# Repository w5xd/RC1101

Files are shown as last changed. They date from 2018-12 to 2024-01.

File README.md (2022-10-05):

# RC1101
Remote control box to add knobs and switches to a PC via USB

3D printed in black and controlling an Elecraft K3 remote.
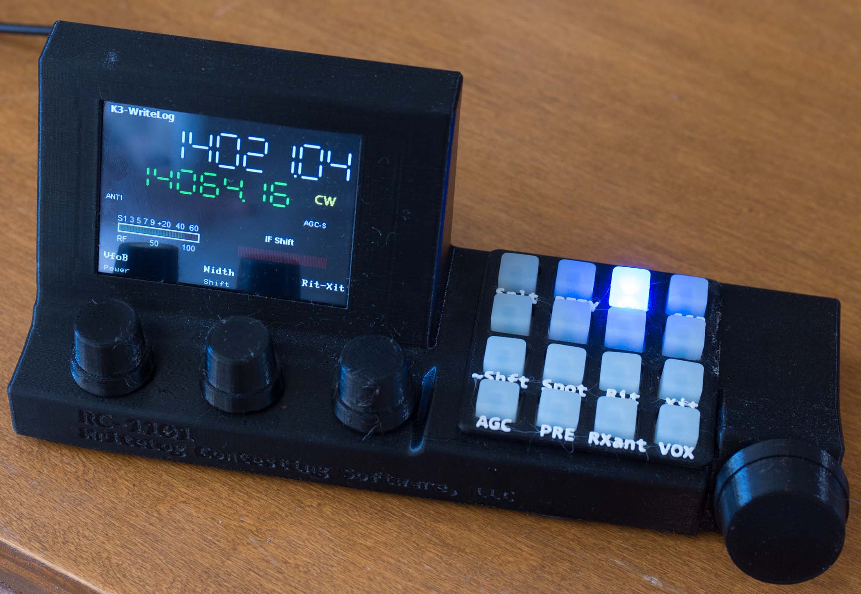
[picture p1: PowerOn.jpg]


This is a build-it-yourself device that WriteLog can use at its control site 
to remote control rigs at your WriteLog-equipped home station. The device can also be used
with WriteLog locally, <i>i.e.</i> at the rig position. (WriteLog restricts your use
of the rig's front panel for the case of RC-1101 control. See the WriteLog documentation.)

Documentation is published here to enable you to:
<ul>
  <li>Fabricate a printed circuit board yourself, or have a service fabricate one for you.</li>
  <li>3D print an enclosure (in three parts.) </li>
  <li>3D print rig-specific keypad overlays</li>
  <li>Parts lists for the remaining, commercially available parts.
  <li>Programming information for its Arduino microprocessor.</li>
  <li>Programming information for its LCD display.</li>
</ul>

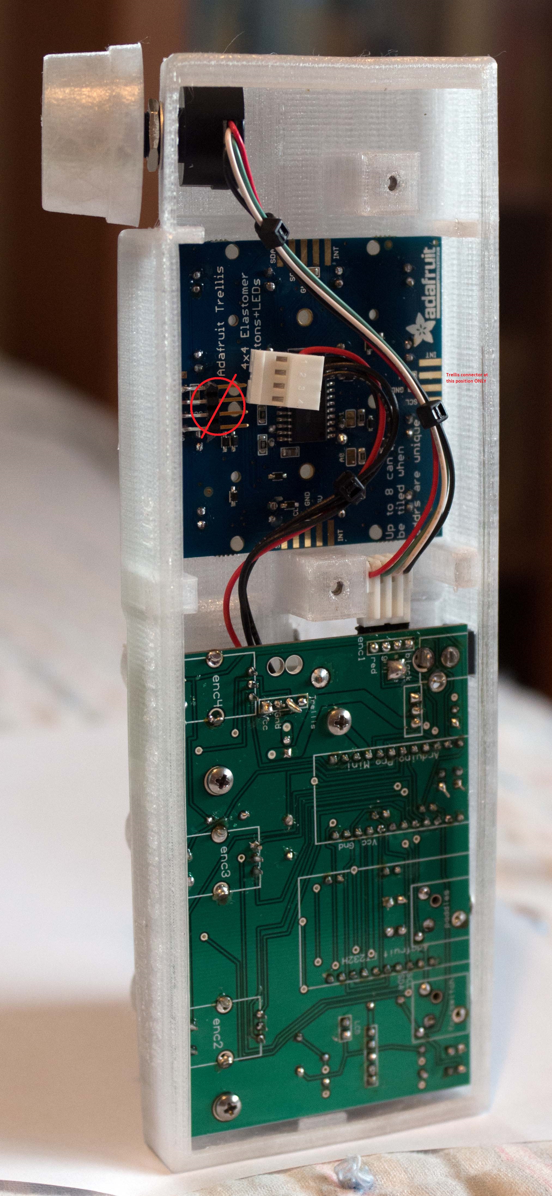
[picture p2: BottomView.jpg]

The enclosure orientation shown&mdash;left hand side down&mdash; is the best one to use for assembly and 
disassembly because the four #4 machine nuts will be retained in their
slots by gravity. Any other orientation risks them falling out.
3D printed using "transparent" PETG. The Adafruit Trellis connector is disconnected for clarity. 
See <a href='construction.md'>construction.md</a> for details.

<h3>Connections</h3>
The back panel has:
<ul>
  <li>DC power. Positive polarity on the center conductor. 7VDC to 9VDC recommended, which dissipates about 1W
  in the TO-220 cased model 7805 5V regulator IC. That part, properly installed with thermal
    grease to the PCB, will stay below 100C up to about 12VDC. The PCB has a 6A rated crowbar
  diode that attempts to protect this circuit against a reverse polarity power supply input. If
    you connect a 35A DC supply to this input backwards...you probably won't like the result.
  </li>
  <li>USB-C. This goes to your PC. WriteLog has support for the RC-1101 over this USB. 
Other software solutions are possible using the open source firmware and PCB on this website. (see <a href='construction.md'>note</a>
about the Adafruit model 2264 old and new. Still-available older parts have micro-USB instead of USB-C,
but both work in the RC1101.)</li>
  <li>Footswitch label on 1/8" phone jack. There is currently no support for this input.</li>
  <li>Paddles label on 1/8" phone jack. There is currently no support for this input.</li>
</ul>
<h3>Printed circuit board</h3>
The layout for the four-layer PCB was done using <a href='http://expresspcb.com'>expresspcb.com</a>.
The file is <a href='WlRemote.rrb'>here</a>.
There are also gerber files <a href='gerber/'>here</a>. 

<h3>Enclosure</h3>
The enclosure was designed using <a href='http://solidworks.com'>Solidworks</a>. 
The Solidworks files are <a href='CAD/'>here</a>.
You don't need Solidworks to print it. The STL files are enough and are
published <a href='STL/'>here</a>. Details about how to print
an enclosure are <a href='enclosure.md'>here</a>.

<h3>Construction hints</h3>
See <a href='construction.md'>this page</a> for construction details.

<br/>Machine screws. 
<ul>
<li>Quantity 8 of #4 by 1/4 inch pan head screws
<li>Quantity 8 of #4 nuts. (square nuts hold in the channel better, but hex nuts fit.)
</ul>

<h3>The keypad, knobs, and LCD</h3>
The Arduino firmware and LCD programming published here work for all supported rigs in a way 
that is customized for each rig. There are conventions in the firmware that at least encourage,
or in some of these cases require, that all rigs behave the same way for these uses:
<ul>
<li>Each button on the keypad represents some function on the rig. Its LED is on to indicate
the function is on, or off otherwise.</li>
<li>The rig driver <i>may</i> program a button to be momentary such that when you press it,
it only blinks on momentarily, and immediately goes back off. This indicates a toggle of 
some function on the remote rig. This is done, for example, for the SPOT function on the 
K3 and K2. Pressing it once turns on the sidetone and pressing it again turns it off.</li>
<li>The biggest knob, to the right, is generally assigned to VFOA, but a given WriteLog
rig driver can change that.</li>
<li>The three smaller knobs not only turn, but also have a momentary contact switch 
that you access by pressing the knob down. The RC-1101 firmware interprets that momentary
press as a command to switch the knob's mode to a second mode. Pressing the switch does not change the
setting of either of the two underlying features on the remote rig.</li>
<li>By convention, the LCD display is programmed to label the knob function at 
the very bottom of its display. And there are two labels for each knob. The
top label is the knob's primary function (the one it has with remote control
is initiated) and the lower label is the secondary function.</li>
<li>The WriteLog rig driver has the capacity to command the RC-1101 as if
you had turned any of its knobs or pressed any of its switches. When the driver
does so, the RC-1101 changes its display state to match. That is, if the driver
commands a button to be pressed, then the LED lights up, in general.
</li>
<li>The LCD display technology is touch sensitive, however the RC-1101
firmware ignores any touches. You may only change the rig by
pressing its switches (the 16 on the keypad, or the 3 under the 
left-hand knobs) or turning its knobs. </li>
</ul>

<h3>Arduino programming</h3>
The device requires the <a href='https://www.sparkfun.com/products/11113'>SparkFun Pro Mini at 5V</a>.
The Arduino sketch is <a href='sketch/wlRemoteGeneric/'>here</a>.

<h3>Gen4-uLCD-32PT programming</h3>
The <a href='https://www.4dsystems.com.au/product/gen4_uLCD_32PT/'>3.2" LCD screen</a> is programmable. The programming 
information is <a href='4D/'>here</a>. The PCB has a 5 pin header with 0.1" spacing to connect to the LCD. It requires the
use of the adapter shipped with the uLCD that converts the 0.5mm FPC cable to 0.1".

<h3>Other</h3>
<a href='WlRemoteCircuit.pdf'>Here</a> is the circuit diagram.

Should you want to use this device without WriteLog, you're going to need
to have some programming on the PC-side of the USB connection to the
RC-1101. <a href='http://github.com/w5xd/RC1101-PC/'>This repository</a> has an example of a .NET program 
for Windows that can access the RC-1101. It uses the libraries
available from <a href='http://ftdichip.com'>ftdichip.com</a>.

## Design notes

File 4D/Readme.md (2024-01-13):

Programming the Gen4-uLCD-32PT for the RC-1101

The LCD device has both a built-in EEPROM program memory and
a micro-SD plugin memory card. The RC-1101 requires <strong>both</strong> be programmed!

Programming the Gen4-uLCD-32PT requires a 4D systems programming cable.
They offer more than one option, and they have changed over time. The
older breakout can program both the old and new LCDs, but the new breakouts have
a connector unique to the Gen4 display.

Use the free IDE from 4D systems to compile the two projects.
https://www.4dsystems.com.au/product/4D_Workshop_4_IDE/

<p>There are (currently) four separate projects to build under the 4D IDE.
The one at Loader32PTU/Loader32PTU.4dg is a loader that you must program into the LCD device
FLASH. It accepts a command over its serial port from the arduino to load a selected
4xe file. This FLASH program in the LCD must be compatible with the ino file in 
the sketch in this same RC1101 source code repository. The other three projects
are rig-specific screen layouts for the RC-1101 LCD.</p>

<p>The workshop files in this directory are identical for those few
RC-1101's built with the older uLCD-32PTU
 device. The 4D Workshop build for the Gen4-uLCD-32PT-AR target as specified in
the .4DGenie projects works fine on those older LCD uSD cards.</p>

The IcomAndFlex.4DGenie project has the screen displays for:
<ul>
<li>A generic form for the case that there is no rig-specific WriteLog driver for the RC-1101.
<li>Icom rigs of the vintage IC-756PRO and newer.
 <li>Flex-6000
</ul>
<p>The 4D workshop build of IcomAndFlex.4DGenie produces a series of files recognizable by their
8.3 DOS file names plus the file IcomAndFlex.4XE.</p>

The TS590andK3.4DGenie has displays for:
<ul>
<li>The same generic form as the above .4D project.
<li>Elecraft K2
<li>Elecraft K3
<li>TS-590
</ul>
<p>The 4D workshop build of TS590andK3.4DGenie produces a series of files recognizable by their
8.3 DOS file names (like the other project above.) And it also creates the file TS590andK3.4xe.
This last file must be renamed TS590.4xe on the uSD card for current WriteLog rig drivers to
specify it. The makeimage.cmd file here does the appropriate file renaming automatically.</p>

The Yaesu.4DGenie has displays for:
<ul>
<li>The same generic form as the above .4D projects.
<li>Recent Yaesu rigs, including the FtDx-10, FtDx-100, FtDX-5000 and others.
</ul>
<p>The 4D workshop build of Yaesu.4DGenie produces a series of files recognizable by their
8.3 DOS file names (like the other project above.) And it also creates the file Yaesu.4xe.</p>

<p>The <code>makeimage.cmd</code> batch file creates a zip file image of what must be copied
to the LCD's uSD card.</p>
<p> The batch file also creates a <code>RunFlash.4xe</code> for 
compatibility with older LCD/Arduino firmware (prior to the WL12.49-Firmware tag in this repository.) 
That older firmware lacks the ability to load a rig-specific 4xe file, and always and only
uses <code>RunFlash.4xe</code>. When you update 
the uSD card on an RC-1101 with the old firmware,  
you must choose which of the rigs it will support by copying the <code>RunFlash.4xe</code>
from one of the 4xe files created above. If you don't know the firmware status,
its safe to copy the appropriate 4xe file to the name <code>RunFlash.4xe</code> on the uSD
card.</p>

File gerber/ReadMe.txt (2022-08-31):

REV02 is obsolete. There is no reason to build it now that REV3 is available.
REV02 has an RC network to filter CW sidetone to the (now obsolete) uLCD-32PTU display.

REV03 is obsolete.
REV03 differs from REV2 in that:
a) it has 4 layers for better RF immunity.
b) it has a place for a 5V sounder for CW sidetone.

REV04 adds SMD pads for all the resistors, capacitors, transistor and regulator

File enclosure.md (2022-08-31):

RC-1101 Enclosure
The enclosure is designed with <a href='https://solidworks.com'>SolidWorks</a>, and the CAD folder is
the SolidWorks design. If you're not going to redesign the enclosure, you
don't need SolidWorks nor what's in the CAD folder. The STL folder contains exported shapes for the enclosures,
<i>almost</i> ready to print on a 3D printer. 
Read the notes below.
The enclosure has these 5 parts to print:
<ol>
	<li>the <a href='STL/enclosure2.STL'>enclosure itself</a>. Do <b>not</b> print this STL file without first 
	understanding exactly what your 3D printer is
       	capable of printing. Do not overlook the cavities
	in the design that accept nuts for #4 nuts. Those cavities are very difficult to clean out if your printing
	process fills them with support material. Hints for printing it on low end
	<a href='https://en.wikipedia.org/wiki/Fused_filament_fabrication#Fused_deposition_modeling'>Fused Deposition Modeling</a> (FDM) printers are below.
	<li><a href='STL/enclosure2 LCD back cover.STL'>enclosure2 LCD back cover.STL</a>
	<li><a href='STL/enclosure2 bottom cover.STL'>enclosure2 bottom cover.STL</a>
	<li><a href='STL/BigKnob.STL'>BigKnob.STL</a>
	<li><a href='STL/SmallKnob.STL'>SmallKnob.STL</a> (print quantity three)
</ol>

In the Trellis directory are the designs for the radio-specific
keypad overlays:
<ul>
	<li><a href='STL/Overlay-Generic.STL'>Overlay-Generic</a> keys used when WriteLog has no specific driver
	<li><a href='STL/Overlay-K2.STL'>Overlay-K2</a> for the Elecraft K2
	<li><a href='STL/Overlay-K3.STL'>Overlay-K3</a> for the Elecraft K3
	<li><a href='STL/Overlay-Icom.STL'>Overlay-Icom</a> For Icom radios, about IC-756 and newer.
</ul>
<h3>Enclosure printing hints</h3>
<p>
The <a href='STL/enclosure2.STL'>enclosure2.STL</a> is the shape you end up with. 
Windows 10 has a viewer for stl. Just click the <a href='STL/enclosure2.STL'>link</a> 
to have a look at it the model. 
On an inexpensive 3D printer, gravity won't let it print in that orientation, and I found I had to model some extra 
supports that break away
after printing. The modeled shape to print on an FDM printer, the one with the orientation that accounts for gravity and
has special supports, is <a href='STL/enclosure42.STL'>enclosure42.STL</a>. 
</p>

<p>Printing this enclosure is not a beginner 3D printing project. It takes a total above 20 hours to print the three of them on my 
<a href='http://prusa3d.com'>prusa I3 MK3S</a> printer. </p>

<p>I used the Prusa recommended slicer, <a href='http://slic3r.org'>Slic3r</a>, to slice the model for printing. The slicer parameters <b>are</b> important for 
the biggest part, <a href='STL/enclosure42.STL'>enclosure42.STL</a>. In particular:</p>
<ol>
	<li>Generate support material is <b>on</b>.</li>
	<li>Support on build plate only is <b>on</b>.</li>
	<li>Various versions of the slicer have given different results with respect to support material. In the current version (PrusaSlicer-2.2.0) I have found that a support material overhang threshold at 20 makes no extra supporting material, but omits the left and right edges of the enclosure. Extra supporting material is a problem because it is difficult to remove. But the left and right edges of the enclosure need supports else they wobble during printing and, at best, have uneven surfaces, but at worse collapse and ruin the print. I used the "support enforcer" option in Slic3r to ensure supporting material on those edges.</li>
	<li>I recommend layer height 0.2mm and the standard 0.4mm nozzle. However, I have successfully printed one in half the time using 0.3mm layer height with a 0.6mm nozzle. But the nut mounting holes are not quite printed square enough, plus it took a lot of my time to fit the LCD into its mounting place because the low resolution print doesn't quite match the shape of the LCD. So use a standard 0.4mm nozzle unless you are practiced with 3D printing and are willing to be extra careful mounting the LCD, and after all that want to save a couple of hours on the printer.</li>
</ol>
The <a href='STL/enclosure2 bottom cover.STL'>enclosure2 bottom cover.STL</a> needs to be printed with:
<ol>
	<li>Generate support material <b>on</b></li>
	<li>Support on build plate only is <b>on</b></li>
	<li>The other cover, <a href='STL/enclosure2 LCD back cover.STL'>enclosure2 LCD back cover.STL</a>, may be printed concurrently. It doesn't need support material but the slicer parameters above won't generate any for the back cover.</li>
</ol>
<p>The three items on this page are the main enclosure. The overlays, and the back and bottom covers can
be printed with default Slic3r settings.  
</p>
I used PETG material for prints destined to actually be used for a device. I used PLA for test prints to 
confirm geometry. A video showing how to remove the support material once printed is posted here:
<p align='center'>
<a href="http://www.youtube.com/watch?feature=player_embedded&v=Ue96Qx1N7DY" target="_blank">youtube Ue96Qx1N7DY</a></p>
<h3>The overlays</h3>
<p>The Trellis keyboard overlays are designed to be printed lettering up with a filament color change anywhere
between Z coordinate above 1.8mm.</p> The text on the overlays comes out far better using a 0.25mm nozzle compared to the standard 0.4mm. I print the overlays with either PLA or PETG filament depending on the color scheme
I want. PETG is the choice when I want the overlay to match the color of its mating enclosure, but PLA is 
easier to deal with, so its a choice for the case you want the overlay printed in a contrasting color.
<h3>Knobs</h3>
All four knobs are for press fit onto a shaft size of 6mm. The 3D printer generally leaves a little debris that can be cleaned out using an undersized drill bit in a bare hand. Rotate the drill bit in the knob's hole while scraping it against all the sides. I used size 15/64 inch.

<h3>Enclosure Cleanup</h3>
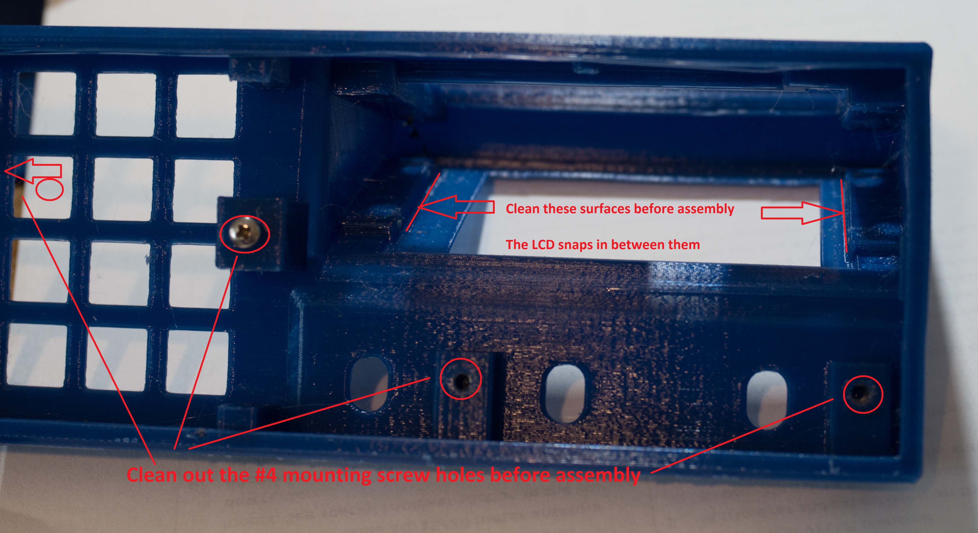
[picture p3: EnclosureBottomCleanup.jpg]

The 3D printing process can leave debris that makes it difficult or impossible to assemble. This
is especially true of the mounting of the LCD. Be sure to use a flat blade screwdriver to
scrape any debris off the surfaces indicated in the photo. Also push a #4 machine screw 
through the 4 mouting holes to clear them as well. Wiggle a small hex key in the nut
slots to loosen the debris.

<h3>Final assembly</h3>
The elastomer pad for the <a href='https://learn.adafruit.com/adafruit-trellis-diy-open-source-led-keypad'>trellis</a> is square, but only two of its possible four orientations lines up its feet into the corresponding holes on its PCB. See this illustration. 
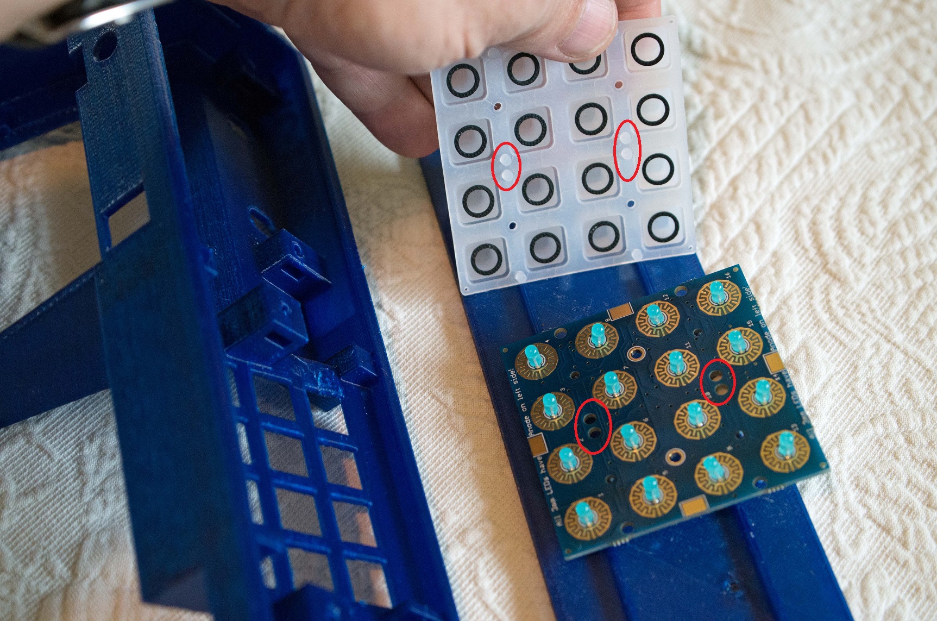
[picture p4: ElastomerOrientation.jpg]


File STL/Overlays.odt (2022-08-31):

Flex-6000

Generic

Icom

K2

K3

TS-590

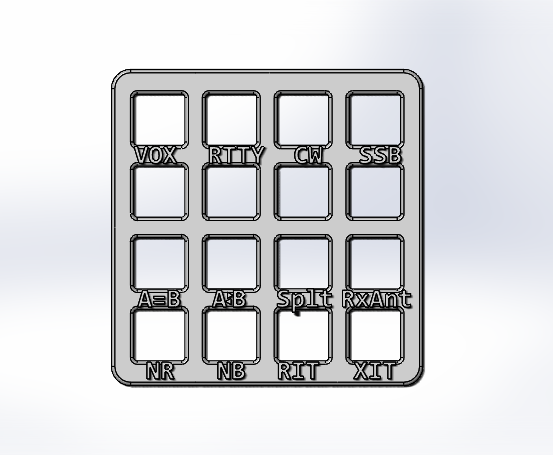
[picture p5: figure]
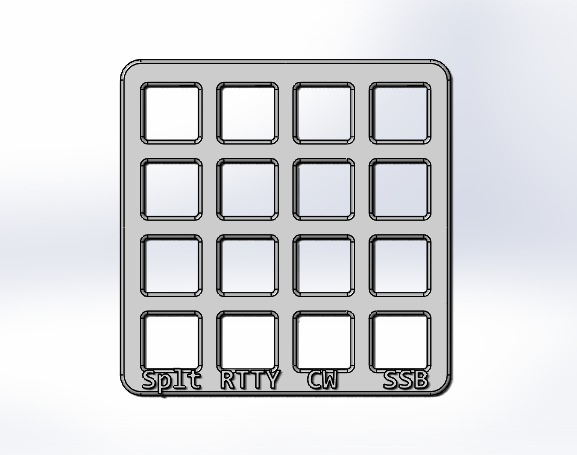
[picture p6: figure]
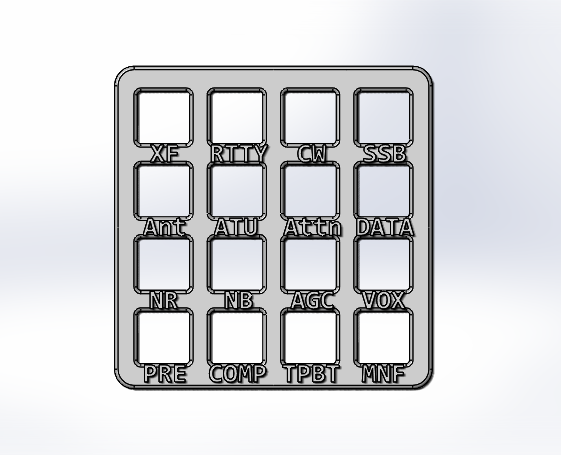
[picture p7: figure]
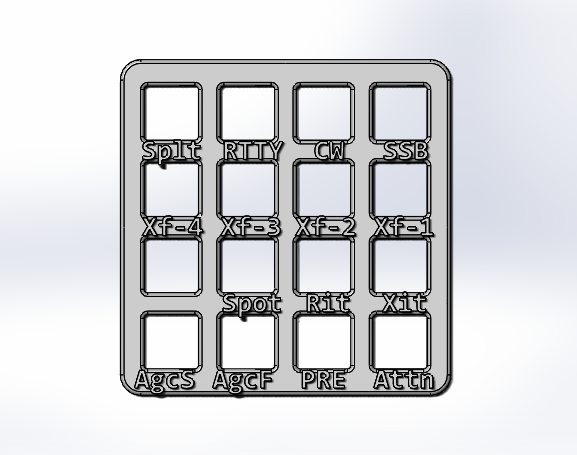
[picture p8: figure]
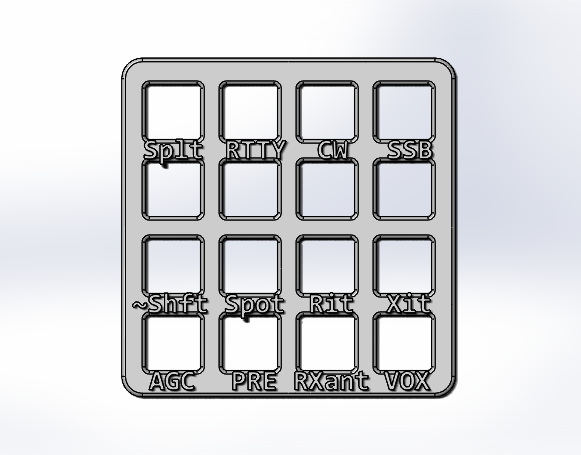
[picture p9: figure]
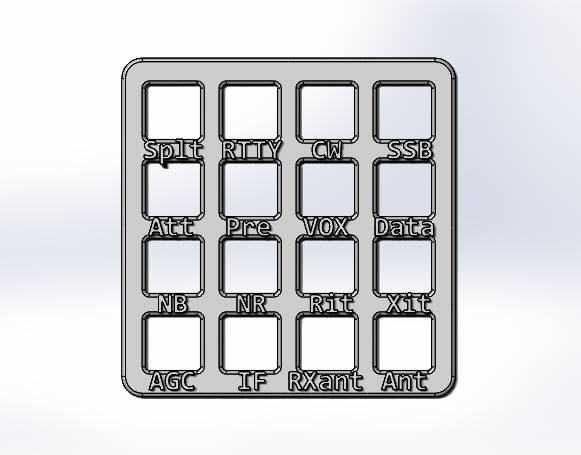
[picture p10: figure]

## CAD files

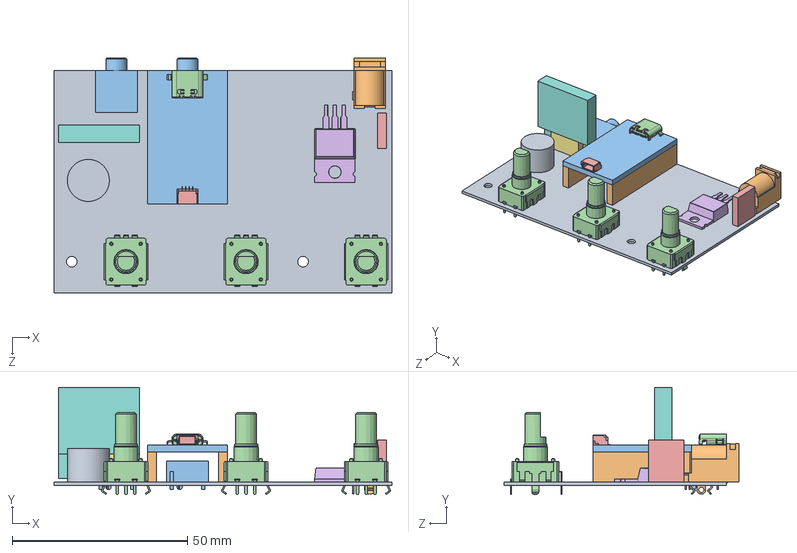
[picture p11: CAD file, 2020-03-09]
CAD/PCB/PcbWithParts.SLDASM
96.5 x 30.6 x 67.0 mm
PCB
CUI_PJ-202A
CUI_SJ-3504 x 2
pec12-encoder x 3
Enc1Header
TO-220 3pins short V1
5PinLcd
gen4-ib
puiaudio
standoff
pcb-ft232
USB-C
quiik

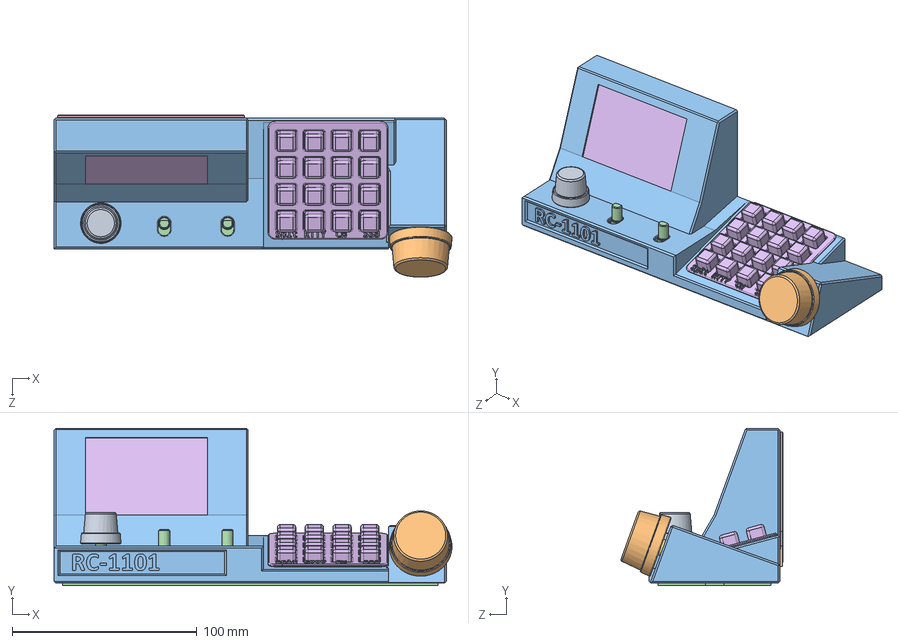
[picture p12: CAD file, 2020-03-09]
CAD/RC1101-4.SLDASM
215.2 x 85.1 x 87.8 mm
PCB
CUI_PJ-202A
CUI_SJ-3504 x 2
pec12-encoder x 3
Enc1Header
TO-220 3pins short V1
5PinLcd
gen4-ib
puiaudio
standoff
pcb-ft232
USB-C
quiik
enclosure2
enclosure2 bottom cover

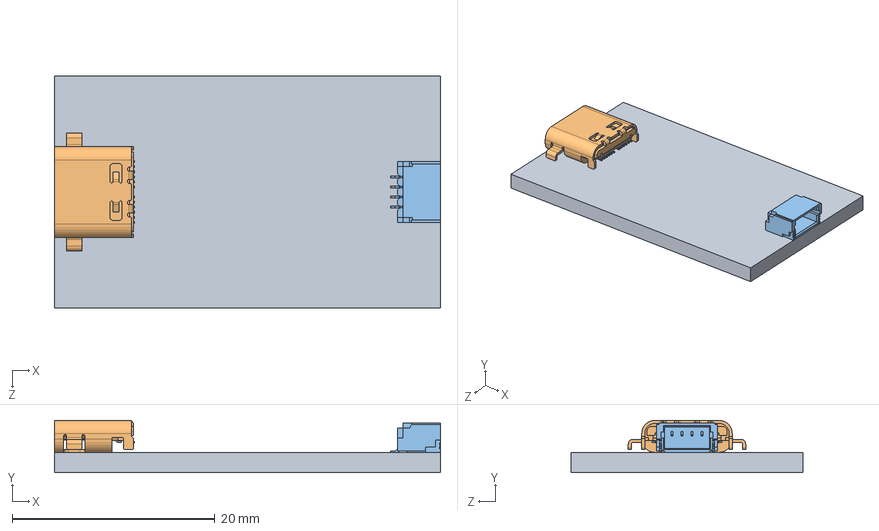
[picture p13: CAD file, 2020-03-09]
CAD/Adafruit232H/Ft232H-2-assembly.SLDASM
38.1 x 5.16 x 22.9 mm
pcb-ft232
USB-C
quiik

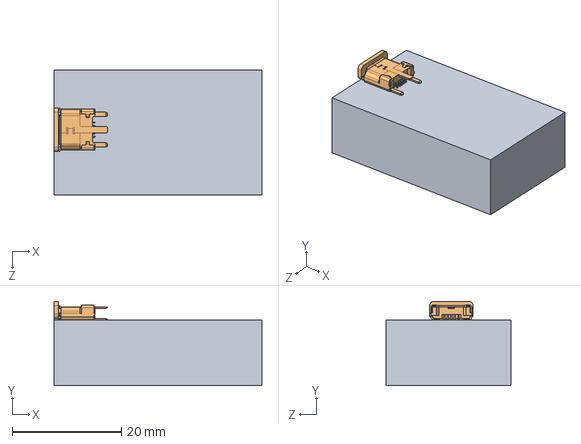
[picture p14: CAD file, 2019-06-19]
CAD/Adafruit232H/Ft232H-assembly.SLDASM
38.1 x 15.4 x 22.9 mm
StandingOff

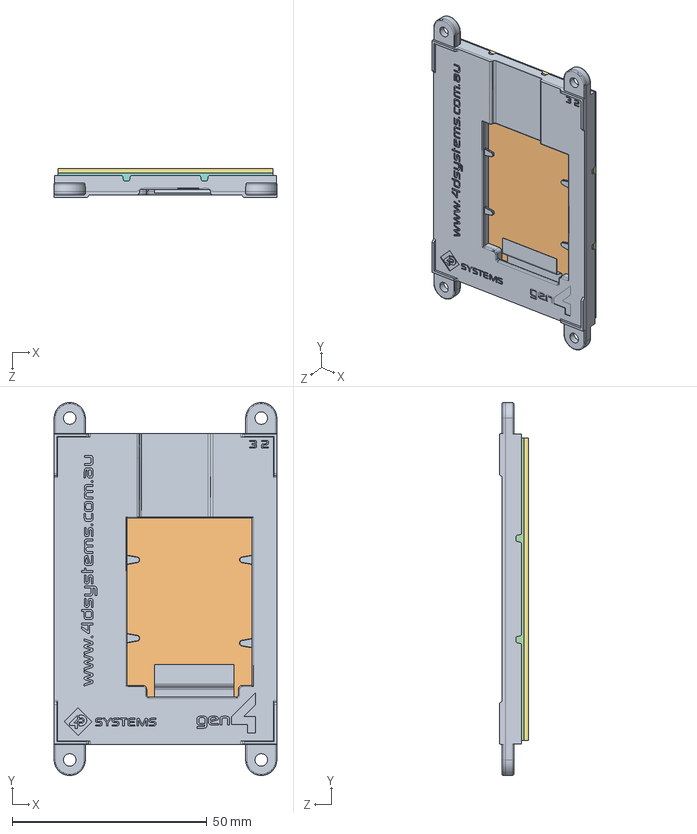
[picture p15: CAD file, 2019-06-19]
CAD/LCD/gen4/Assembly-32PT-NoPCB_2.sldasm
57.1 x 95.7 x 7.49 mm
gen4-32-PT_2
4DLCD-32T-QVGA-BASE
4DLCD-32T-QVGA-LCDGLASS
4DLCD-32T-QVGA-METAL
4DLCD-32T-QVGA-BASE_1
4DLCD-32T-QVGA-LCDGLASS_1
4DLCD-32T-QVGA-GLASS-RTP_1
4DLCD-32T-QVGA-METAL_1
4DLCD-32T-QVGA-FLEX-Gen4_1

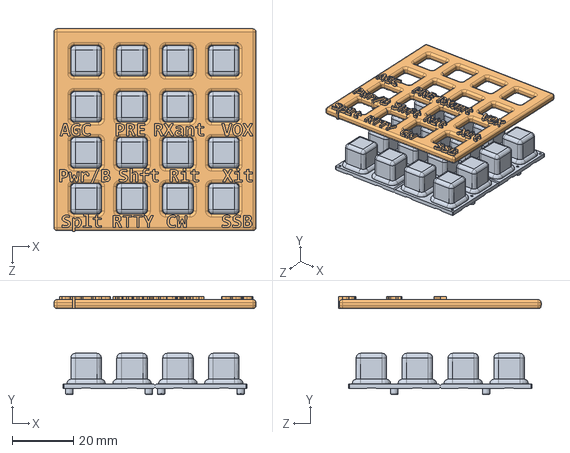
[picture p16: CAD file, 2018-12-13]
CAD/Trellis/TrellisOverlay.SLDASM
66.0 x 32.0 x 66.2 mm
Adafruit Trellis 3mm
Overlay-K3

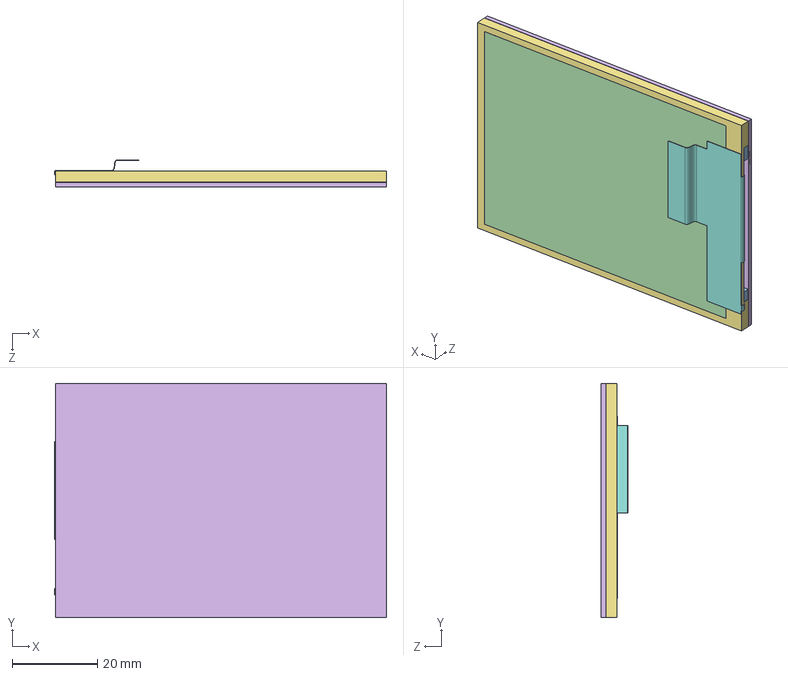
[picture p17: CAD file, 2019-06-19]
CAD/LCD/gen4/4DLCD-32T-QVGA-LCD_2.sldasm
78.0 x 55.0 x 6.37 mm
4DLCD-32T-QVGA-BASE
4DLCD-32T-QVGA-LCDGLASS
4DLCD-32T-QVGA-METAL
4DLCD-32T-QVGA-BASE_1
4DLCD-32T-QVGA-LCDGLASS_1
4DLCD-32T-QVGA-GLASS-RTP_1
4DLCD-32T-QVGA-METAL_1
4DLCD-32T-QVGA-FLEX-Gen4_1

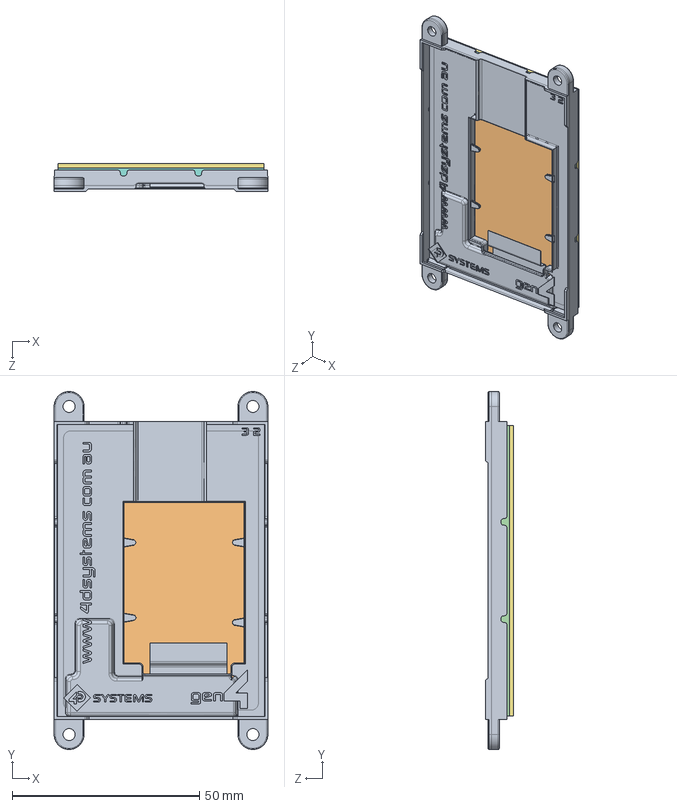
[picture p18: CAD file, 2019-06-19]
CAD/LCD/gen4/gen4-uLCD-32PT.SLDASM
57.1 x 95.7 x 7.49 mm
gen4-32-PT_2
4DLCD-32T-QVGA-LCDGLASS
4DLCD-32T-QVGA-LCDGLASS_1
4DLCD-32T-QVGA-GLASS-RTP_1

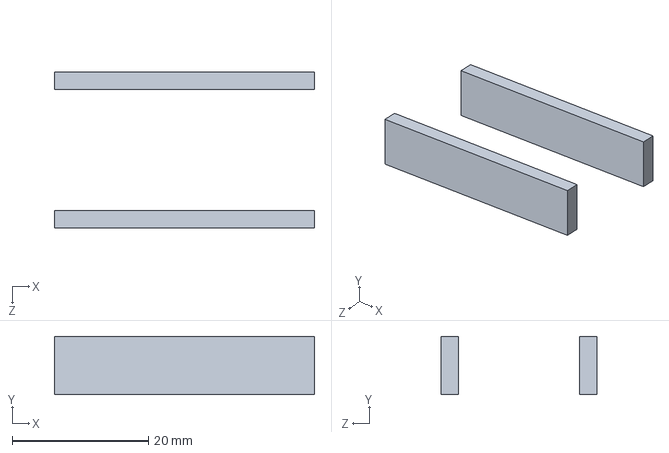
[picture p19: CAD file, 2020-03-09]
CAD/Adafruit232H/standoff.sldprt
38.1 x 8.50 x 22.9 mm

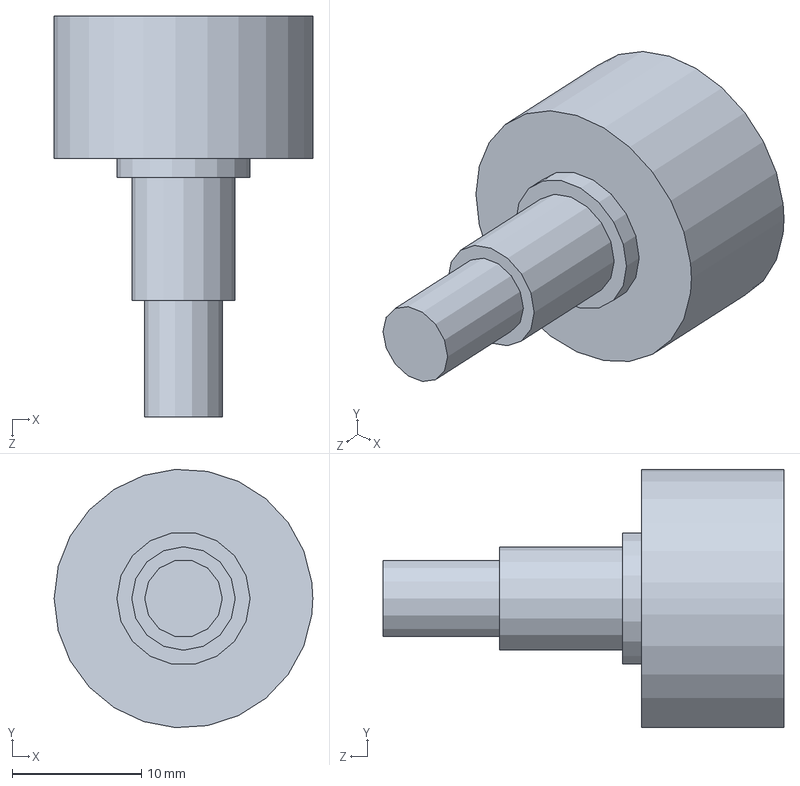
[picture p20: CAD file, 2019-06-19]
CAD/Copal/Copal-encoder.SLDPRT
20.0 x 20.0 x 31.0 mm

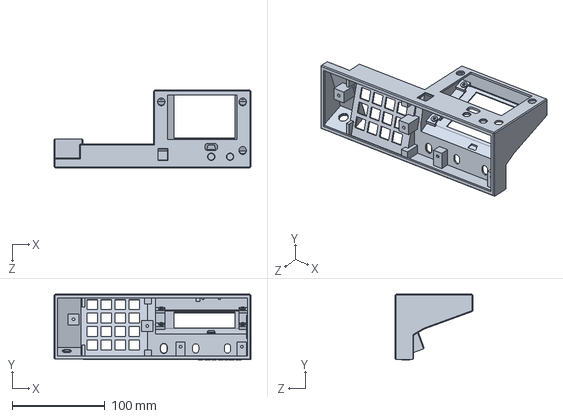
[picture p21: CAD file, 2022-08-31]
CAD/Enclosure/enclosure2.sldprt
212.2 x 70.9 x 83.7 mm

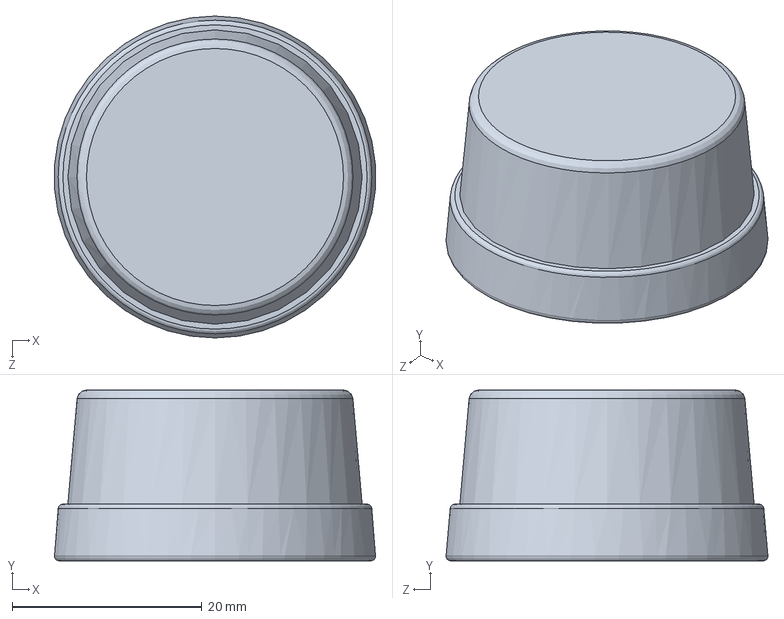
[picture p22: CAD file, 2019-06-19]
CAD/knobs/BigKnob.SLDPRT
33.8 x 18.0 x 33.9 mm

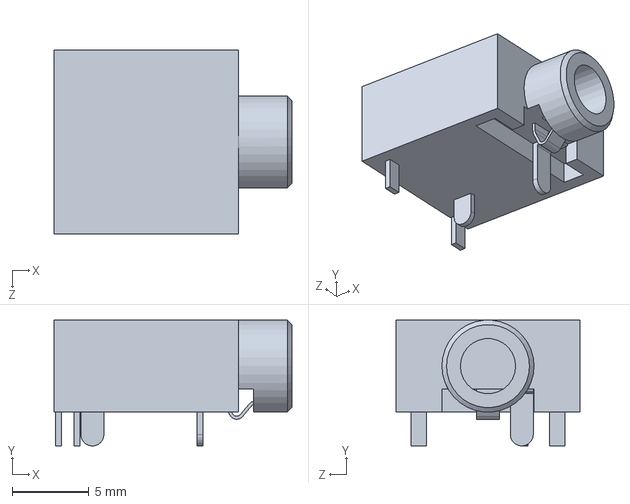
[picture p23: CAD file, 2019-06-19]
CAD/pec12/CUI_SJ-3504.sldprt
15.5 x 8.20 x 12.0 mm

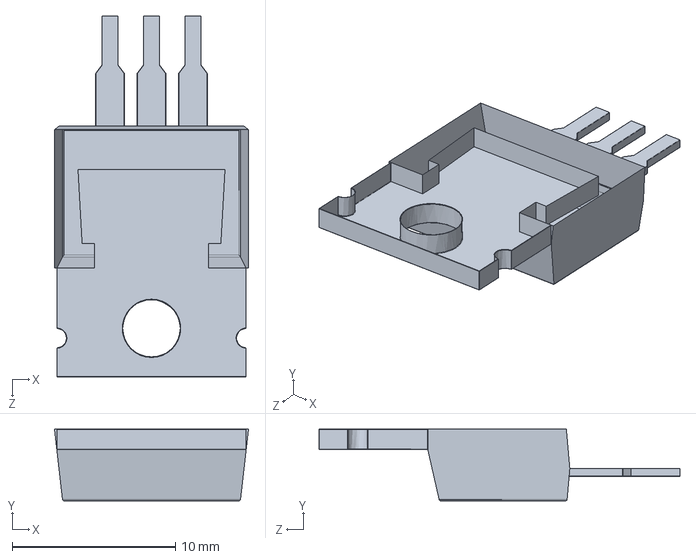
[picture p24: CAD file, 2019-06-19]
CAD/TO220/TO-220 3pins short V1.SLDPRT
11.9 x 4.40 x 22.1 mm

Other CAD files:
CAD/LCD/gen4/4DLCD-32T-QVGA-GLASS-RTP_1.sldprt
CAD/Trellis/Overlay-Blank.stp
STL/Overlay-Generic.STL
CAD/Adafruit232H/StandingOff.SLDPRT
CAD/Adafruit232H/1051330001.SLDPRT
CAD/Adafruit232H/1051330001.stp
CAD/Adafruit232H/USB-C.SLDPRT
CAD/Adafruit232H/USB-C.stp
CAD/Adafruit232H/pcb-ft232.SLDPRT
CAD/Adafruit232H/quiik.SLDPRT
CAD/Adafruit232H/quiik.stp
CAD/Enclosure/enclosure2 LCD back cover.sldprt
CAD/Enclosure/enclosure2 bottom cover.sldprt
CAD/LCD/gen4/4DLCD-32T-QVGA-BASE.sldprt
CAD/LCD/gen4/4DLCD-32T-QVGA-BASE_1.sldprt
CAD/LCD/gen4/4DLCD-32T-QVGA-FLEX-Gen4.sldprt
CAD/LCD/gen4/4DLCD-32T-QVGA-FLEX-Gen4_1.sldprt
CAD/LCD/gen4/4DLCD-32T-QVGA-GLASS-RTP.sldprt
CAD/LCD/gen4/4DLCD-32T-QVGA-LCDGLASS.sldprt
CAD/LCD/gen4/4DLCD-32T-QVGA-LCDGLASS_1.sldprt
CAD/LCD/gen4/4DLCD-32T-QVGA-METAL.sldprt
CAD/LCD/gen4/4DLCD-32T-QVGA-METAL_1.sldprt
CAD/LCD/gen4/gen4-32-PT_2.sldprt
CAD/PCB/5PinLcd.SLDPRT
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

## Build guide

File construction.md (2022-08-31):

<h3>Parts List</h3>
<p>See a PDF of the parts <a href='partslist.pdf'>here</a>. Or link to the digikey shared shopping cart from 
<a href='https://www.digikey.com/short/z84fb8'>here</a>.</p>
<p>Note that the specified female headers have a 0.29 inch insulation height. This, combined with the 0.10 inch insulation height on the matching male header, is a critical dimension
for the Adafruit FT232H breakout board. The USB port on that board will not line up with its matching hole 
in the enclosure otherwise. Also note that Adafruit has put their same part number, 2264, on both an older 
version of the board with a micro-USB connector,
and a newer version with a USB-C connector. Both the old and new Adafruit boards will fit this PCB and 
enclosure, but of course you'll need a different cable.</p>

<h3>Construction hints</h3>
<p>
Fully assemble the two printed circuit boards. </p>
<p>The custom 3.5 inch by 2.8 inch printed circuit board has holes for through-hole components at all
positions combined with SMD 1206 pads for all the resistors and capacitors plus SMD pads for
the transistor, voltage regulator and crowbar diode. We don't
offer step-by-step kit instructions, but here is an order of assembly that accommodates being able to
place the through-hole components and solder them without them falling out (much). The photos
below do not exactly match the order the text describes installing the components. The order is not
critical, except that taller components should be installed later, and the resistors and capacitors
can be installed almost any time without interference with other components. </p>
<ul>
<li>If you're using SMD components, apply solder paste and place all the resistors, capacitors, transistor,
voltage regulator, and crowbard diode and reflow solder them. And skip the steps below describing when to
install them through-hole.</li>
<li>Instructions for the Adafruit Trellis are
<a href='https://learn.adafruit.com/adafruit-trellis-diy-open-source-led-keypad/adding-leds'>here</a>.</li>
<li>Add the right angle 4 pin SMD header. There are four sets of pads that look like you can connect but <i><strong>the position in the photo is the only position it will fit in the enclosure.</strong></i>
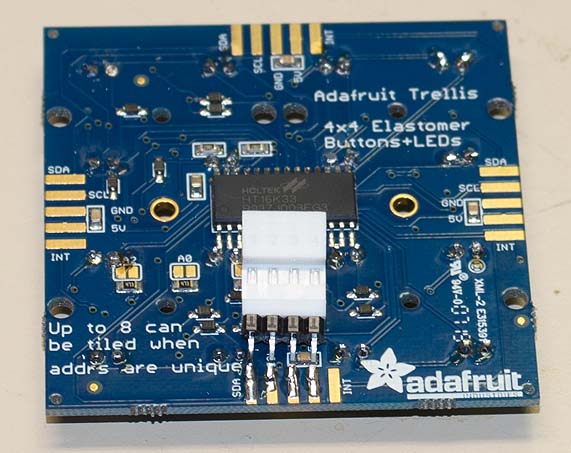
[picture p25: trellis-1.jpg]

Temporarily place the 4-pin connector as a spacer to ensure you have room to install it later.
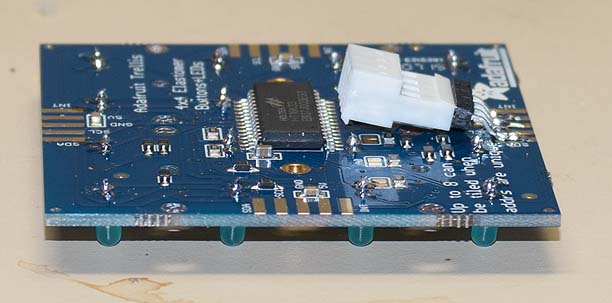
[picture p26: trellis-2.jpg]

 </li>
<li>Smallest parts go on the PCB first.
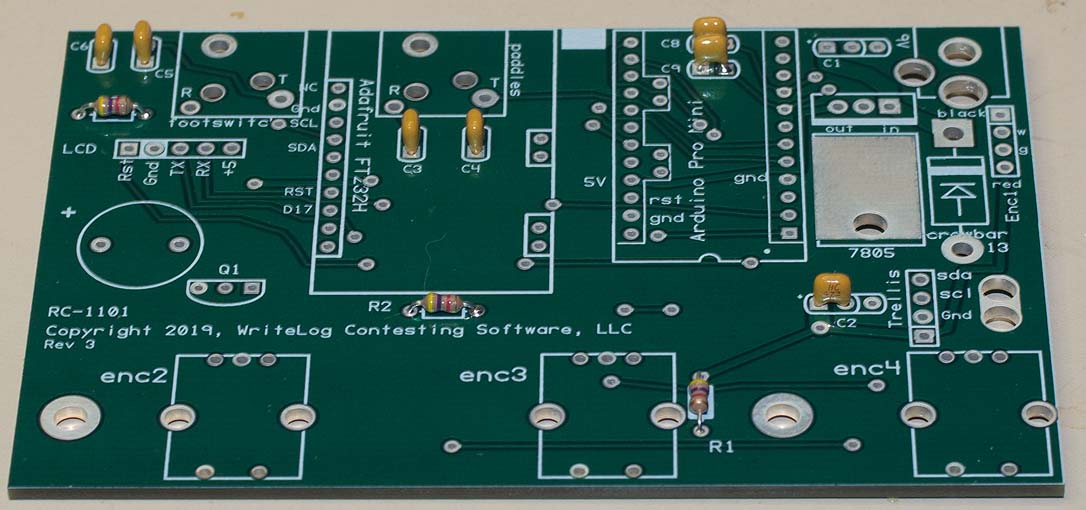
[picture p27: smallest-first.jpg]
</li>
<li>Install a right angle male header at enc-1. The pins extend out beyond the edge of the PCB.
	<li>the two 1/8" mini jacks, J2 and J2.
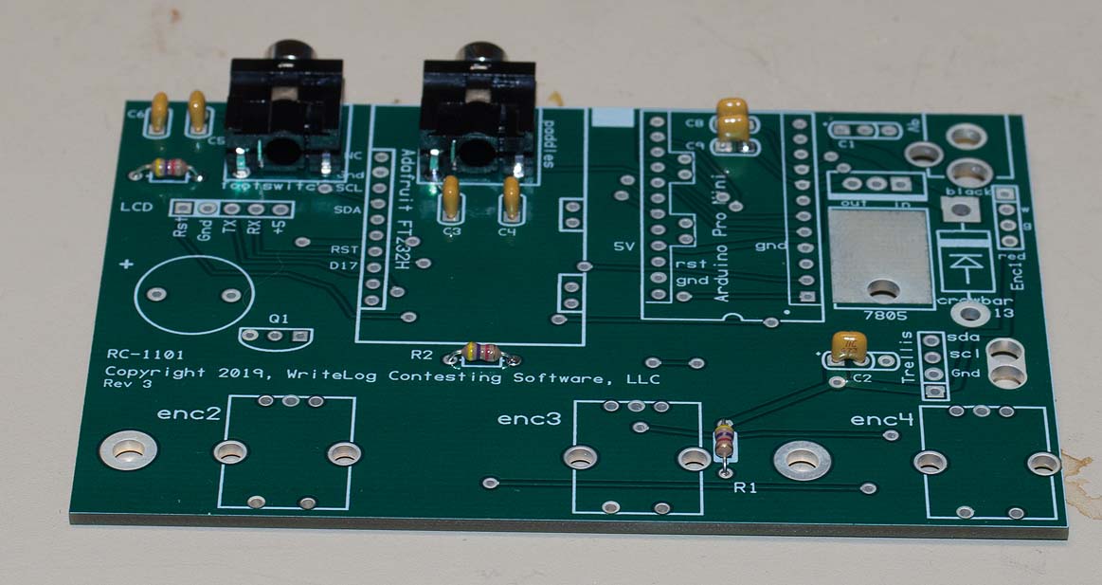
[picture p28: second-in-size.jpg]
</li>
	<li>Assemble the two 12 pin, .1" centered female connection headers for U2, and their corresponding
       12 pin male connection headers. Don't solder yet.
       <li>Add the two 2 pin headers, both male and female, for the A6/A7 and SDA/SCL pins for U1.
       <li>Solder <i><b>only</b></i> the four corner pins (D1, D9, D10 and RAW) on both the top of the Arduino board
and the bottom of the PCB. double check that all pins are aligned and pushed all the way in. 
Triple check. Its much more difficult to correct errors after this.
<li>Now solder all U2 pins on the top of the Arduino and the bottom of the PCB.
</li>
<li>With the Arduino pulled out of its PCB socket, install a right angle male 6 pin programming header. 
<b>Important:</b> The header <b><i>must hang from the bottom of the Arduino board</i></b>. It will not clear the enclosure if mounted on top.
<li>Cut the headers for the RS232H part to the approppriate number of pins, both the socket side and the pin side. The total offset of the RS232H from the PCB must be 0.390 inches (25/64 inches, or 9.9mm)
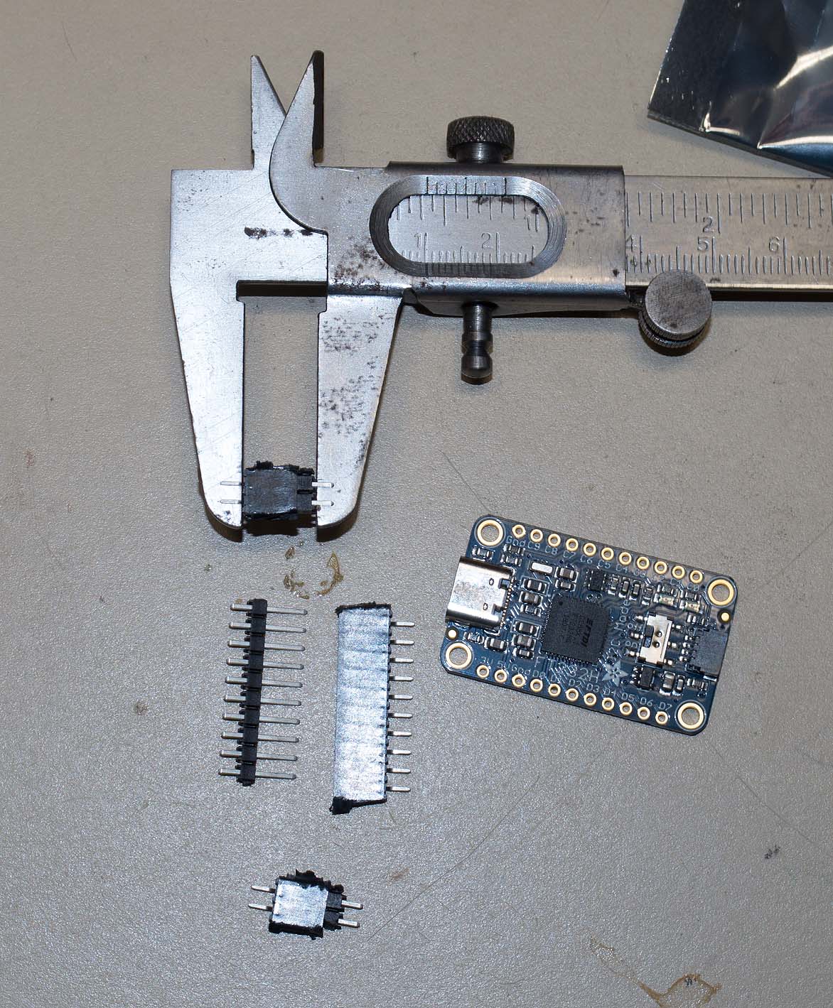
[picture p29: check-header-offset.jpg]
</li>
<li>Use a similar procedure for installing the headers U1 as you did for U2 above. It has 10 pin headers--a female and a male--and has to be soldered
on top of the Adafruit FT232H board and on the bottom of the PCB. Solder the four corners first.
Double check that all the pins are populated and pushed all the way in.
<li>triple check. you won't get another chance. Now solder all the pins for U1.
<li>Pull the Arduino and the FT232H boards and set them aside while working on the remainder.
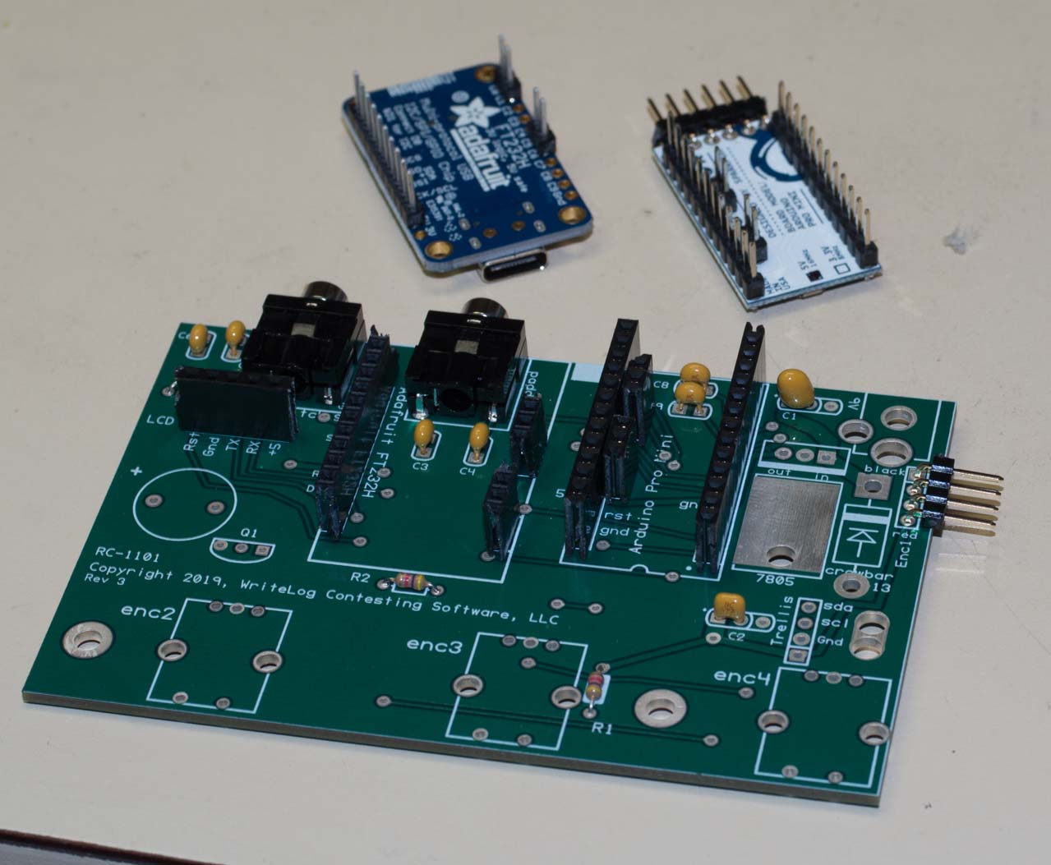
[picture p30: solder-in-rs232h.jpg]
<li>Install a female header at J5 (5 pins) 
<li>Install the buzzer/sounder. Observe the PLUS pin! The buzzer will be destroyed if its backwards.
<li>Install the J15 power jack.
<li>U14 has 3 leads that extend through the board and its TO-220 package <b>must</b> be bent over 
with the hole on its tab matching the hole in the PCB. It dissipates about 2W and will 
overheat if not bonded properly to the PCB.
<li>put a very small dot of heat sink grease on U14 to thermally bond it to the matching PCB
area with no solder mask.
<li>Fasten it with a 4-40x1/4" screw and #4 nut. Assemble the nut on the bottom of the PCB to save yourself trouble later
when you need to avoid confusing it with the screws that hold the PCB in the enclosure. 
<li>All the resistors R1 through R3 are the same value, 4.7K
<li>The power supply has the large diode D13, the polarized 1.0 uF capacitor C1 and the 5V output, 0.047 uF, C2.
<li>C3, C4, C5, C6, C8, C9 are all .001uF
<li>Install Q1
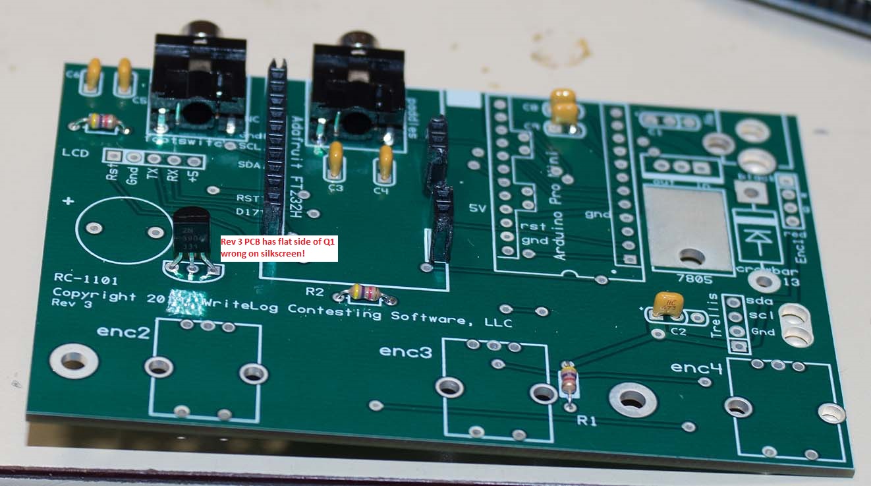
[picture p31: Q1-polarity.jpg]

Install the 2N3904 at Q1. REV3 of the PCB has the silk screen flat backwards! The collector goes in the square pin.
<li>Regarding the 4-pin female 0.100" connector used in both subsequent steps. It is specified as an "IDC" part, which
means "insulation displacement." I came to the conclusion that the correct wire for these connectors is made 
of pure unobtainium but also found that the plastic housing can tolerate a soldering iron. That is: strip the
wires for these connectors, press them into position on the header and melt a solder bead.</li>
<li>Install a 4 pin female connector on the leads from the panel mount optical encoder.
Observe the color designations on the PCB. The black wire goes into pin 1.
Don't shorten the encoder wires. Press their
stripped ends into the connector housing. The best tool is <a href='https://www.digikey.com/short/zjvqw2'>this one</a>. Or use a small allen key or similar tool.
<li>Solder 4 wires of about 4 inches length and 24 gauge in the J4 holes labeled Trellis.
I use three wires the same color and a distinct color for VCC.  
<li>Assemble the 4 wires from J4 into a 4 pin female header. Maintain the same order as on
the PCB. Pin 1 on the header (use a magnifying glass) is the 5V pin.
<li>Use two nylon cable ties to bind the 4 wires together on each of the 4-wire harnesses:
the one to the Trellis and the one to the panel mount encoder.
<li>Install the 3 PCB mount encoders. solder all the pins. There will be significant
force trying to pull these back out of the board in the future if and when it becomes necessary to remove
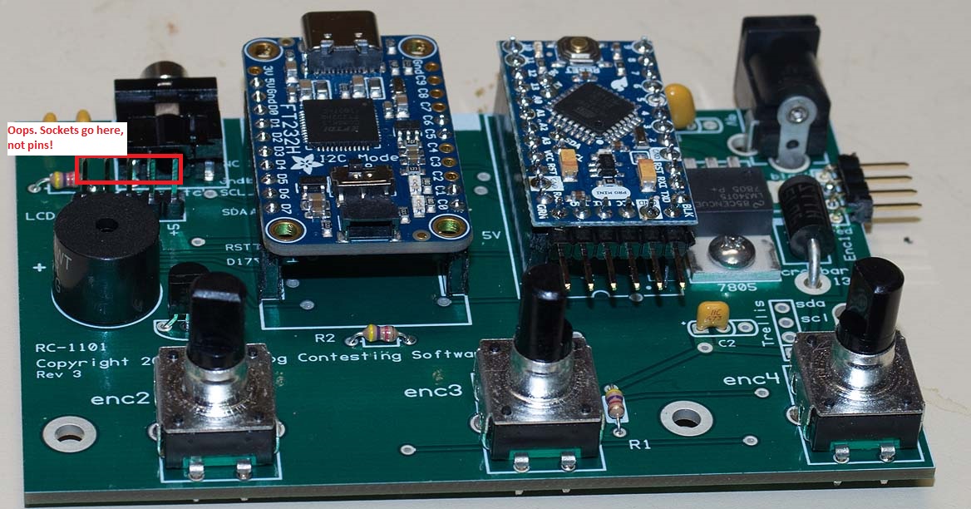
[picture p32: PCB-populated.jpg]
the knobs pressed on them. 
It is important that the encoders be pressed tightly flat against the PCB. The shaft will not line up properly with the
enclosure hole otherwise.
<li>Assemble the LCD display. The FFC cable connectors on the 4D systems parts are very small. Look at the photo carefully. 
The RC-1101 needs the gen4-IB 
(interface board) installed both for programming and to install the RC-1101. Get it
on that FFC cable and it can stay there.
The locking tab slides towards the "gen4 Display" logo to unlock.
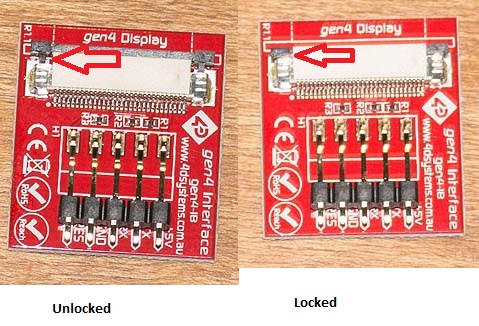
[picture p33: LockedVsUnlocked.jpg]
</li>
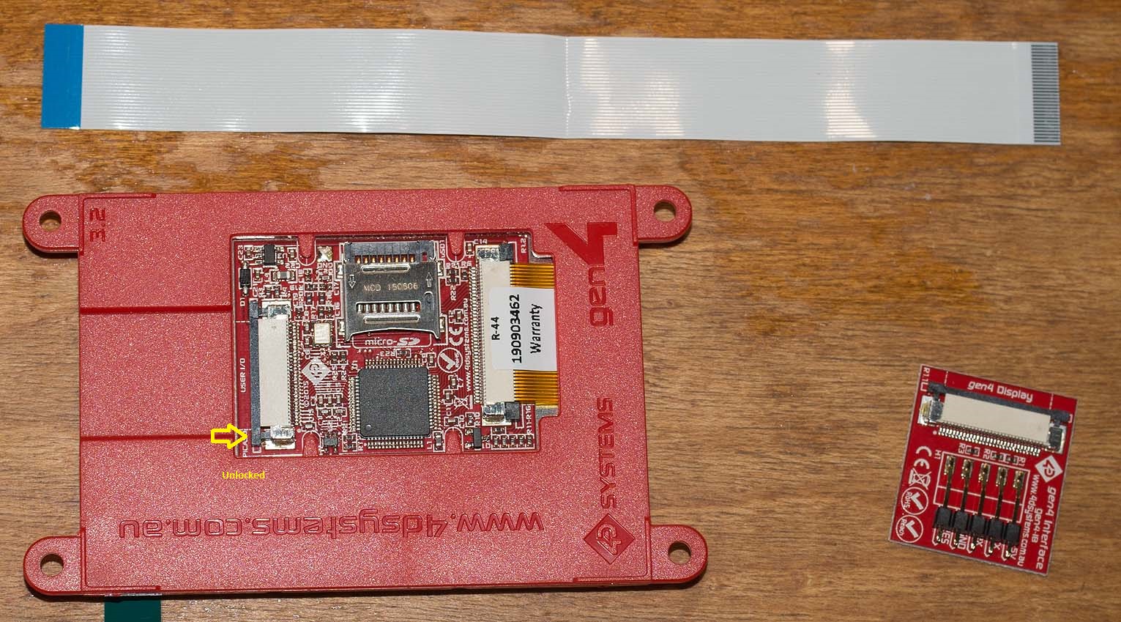
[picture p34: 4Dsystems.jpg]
</li>
</li>
<li>When you get the connectors installed correctly and connect it to the programmer and a PC, the
3.2" screen lights up.
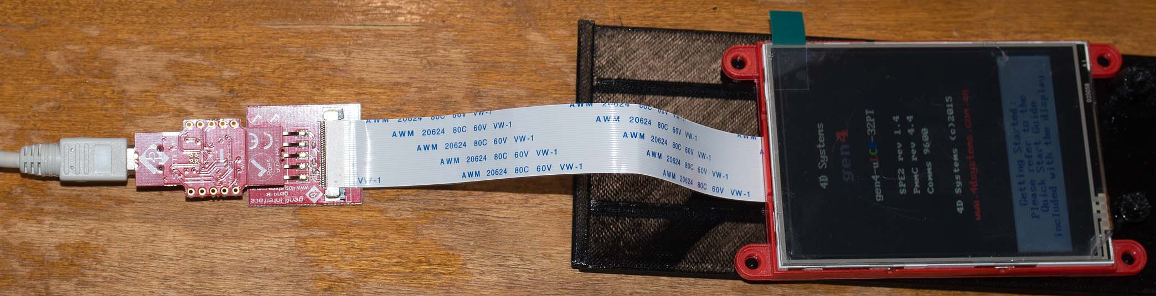
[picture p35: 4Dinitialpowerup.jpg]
</li>
</li>
<li>A FAT formatted uSD card is installed. The primary partition must be no more than 4GB.
As of this writing, Windows 10 has no simple GUI to accomplish this on larger (and more common)
uSD cards. To limit a partituion to 4GB and FAT format, you must use diskpart run as an administrator, which is <string>dangerous</strong>.
One wrong keystroke and you will destroy your PCs boot drive. <a href='https://superuser.com/questions/202160/how-do-i-format-my-8-gb-usb-drive-to-fat-fat16-in-windows-7#answers'>Here</a> are some instructions. <strong>The dangerous step is the <code>select disk 1</code> command</strong>. You must select the correct disk! One more hint: I found it helps to insert one more command after the "clean" command in those instructions: "<code>convert mbr</code>".  The LCD cannot mount a uSD card
with a fancy new partition table, only master boot record will do.
 
Copy the contents of the file WL1244-gen4.zip onto the card.
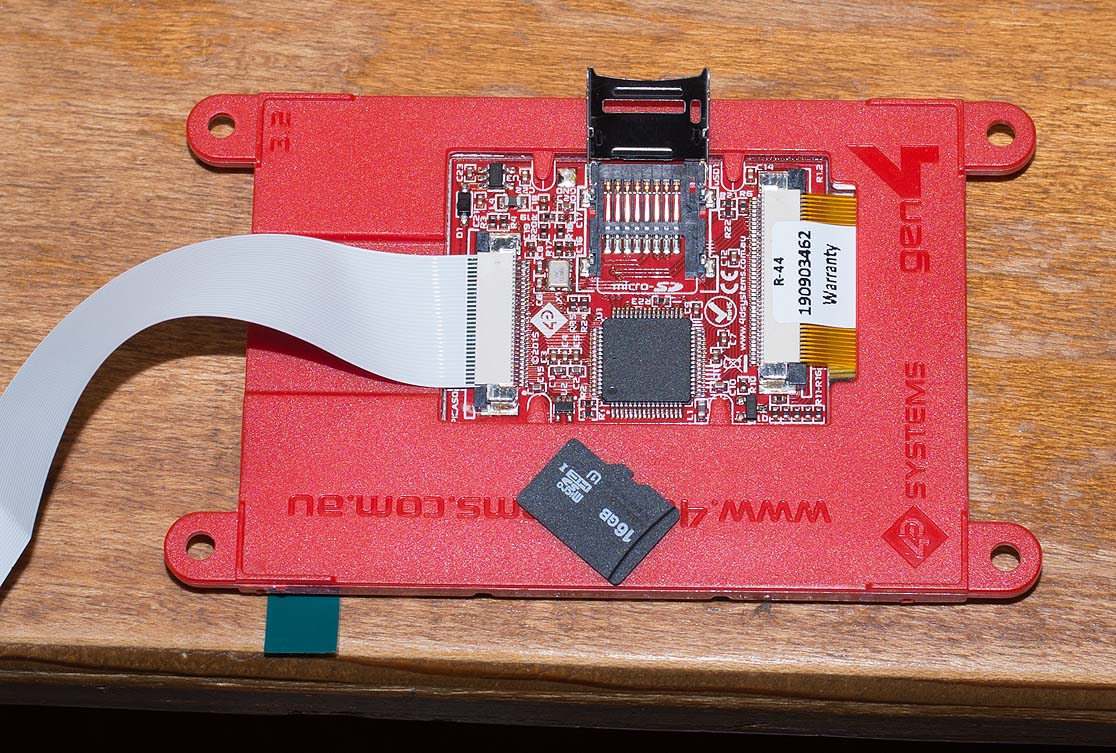
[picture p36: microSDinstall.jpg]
</li>
</li>
<li>Details about the enclosure are <a href=enclosure.md>here</a>.</li>
<li>The enclosure prints with a substantial amount of support material. It is easy to remove, but it helps to know exactly where to grab and twist. See <a href='https://youtu.be/Ue96Qx1N7DY'>this video</a>.</li>
</ul>

Once the PCB is assembled, here is a photograph of the parts (REV 2 device):
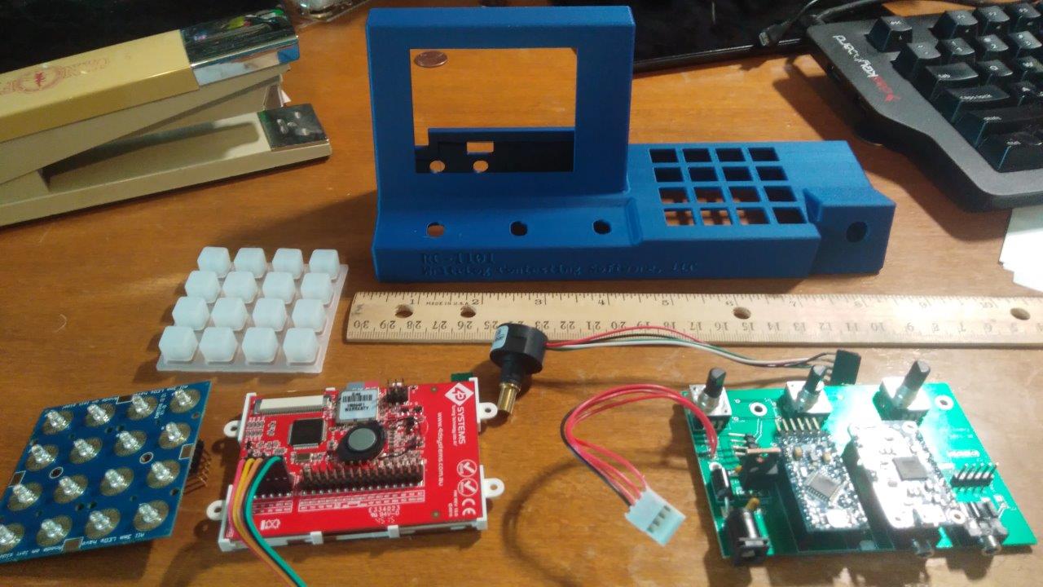
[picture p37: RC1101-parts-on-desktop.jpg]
 

<h3>Older LCD</h3>
You are reading the documentation for design that uses the gen4 display device, the gen4-uLCD-32PT. There exists an
older uLCD-32PTU device which has different mounting dimensions and therefore different STL files to print an enclosure.

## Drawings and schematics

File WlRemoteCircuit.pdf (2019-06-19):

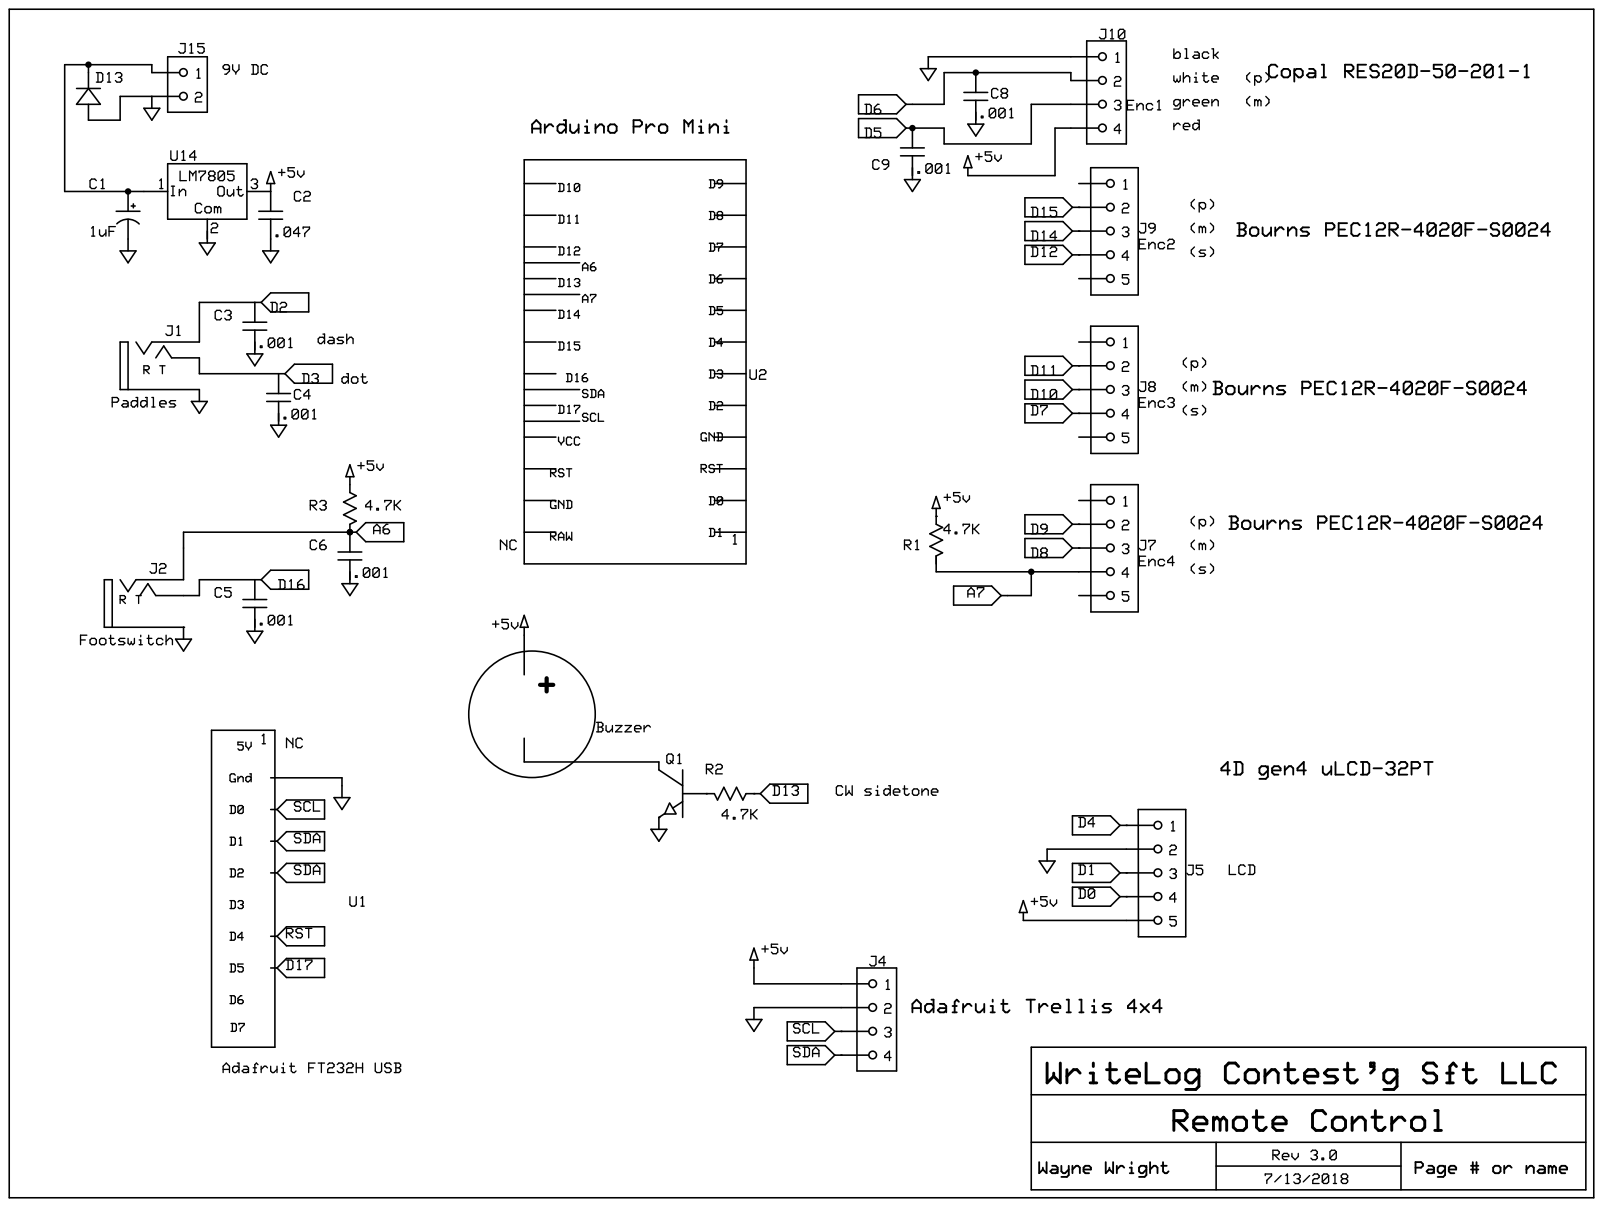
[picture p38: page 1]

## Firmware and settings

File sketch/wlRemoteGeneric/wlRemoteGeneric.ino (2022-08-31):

#include <genieArduino.h> // 4D systems display--unmodified.
#include <EEPROM.h>
#include "SAdafruit_Trellis.h"  // modified manufacturer's library to use twi.cpp directly 
#include "twi.h" // modified 2-wire driver for AVR

/* This is the firmware for the WriteLog Remote front panel, RC-1101.
**
** The arduino Pro Mini 5V is required. 
**    The compile-time variations for the Mega helped with development.
**
** The arduino is connected to:
**    4dsystems uLCD-32PTU display (3.2 inch) (via the serial port)
**    Adafruit Trellis 4x4 keyboard with LED indicators (via i2c)
**    ftdichip FT232H on Adafruit break-out board (via i2c)
**    up to 4 rotary encoders. via 2 arduino pins each.
**    3 of the 4 encoders may have push-to-activate switches (via 1 pin for each)
**
** There is no rig-specific functionality here. Instead, it is all "soft"
** The rig-specific functionality comes from the combination of:
** (a) rig-specific programming of the uLCD-32PTU display
** (b) rig-specific setup over the USB port via the FT-232H
**
** A Win32 dll, RadioPanelUSB, is published with this sketch. RadioPanelUSB
** is a Win32 implementation using ftdichip's published ftd2xx dll interface
** to talk to the FT232H chip. The combination achieves roughly 15 bytes
** of transfer in both directions every 15 msec.
**
** The i2c interconnect has the advantage of consuming only 2 wires to accomplish
** USB communications with the host along with 16 key button input + 16 LEDs, one
** for each button.
** 
** ...but it is complicated by the fact that the FT-232H can do i2c only as a bus
** master but CANNOT do i2c multi-master arbitration, while the Trellis operates 
** only as a bus slave. The Arduino can do either (one at a time.) The result
** is a modified version of the AVR code for twi that is unique to this sketch and in
** twi.cpp. The twi modification required like modifications to Adafruit's trellis
** library, and that modified version is also part of this ketch.
**
** Keeping the FT-232H off the i2c bus while the arduino is the master consumes
** a 3rd pin, so its not really a "2-wire" interface here.
*/

// to help debug interactions between devices, the following compile systems
// include/omit the Genie, i2c-to-pc,  trellis, and use of Serial for debugging messages
#define DO_GENIE // the 4Dsystems display
#define DO_PC_I2C // i2c to the FT-232H, arduino is slave
#define DO_TRELLIS  // i2c to the trellis. arduino is master
#define SERIAL_DEBUG
#if defined(DO_GENIE)
#undef SERIAL_DEBUG // cannot have both genie and serial debug...on Pro Mini anyway
#endif
#define NUMBER_OF_ROTARY_ENCODERS 4 // Must be 1, 2, 3, or 4
// encoder1 has no switch, but the other 3 have a second map
#define NUMBER_OF_ENCODER_MAPS ((NUMBER_OF_ROTARY_ENCODERS * 2) - 1) 

#define ENCODER3_AND_4_HANDLING 2 // 0 is poll. 1 is PCINT0, 2 is on a timer interrupt
// for reasons I have been unable to track down, the "pin change interrupt" value, 1 crashes
// the arduino randomly.

static const int32_t LOWEST_INT32 = 0x80000000;
static const int32_t HIGHEST_INT32 = 0x7fffffff;

template <uint8_t ENC_PLUS, uint8_t ENC_MINUS,
        uint8_t SWITCHMMASK>
class QuadratureEncoder
{
    // each instance of this object is for one physical
    // encoder, but holds two states, one for each 
    // each switch position.
public:
    QuadratureEncoder();
    void OnEncoder(uint8_t);
    void SetEncoderCenter(int32_t p);
    void SetEncoderCenter2(int32_t p);
    void ResetEncoderCenters() 
    {SetEncoderCenter(0); SetEncoderCenter2(0); SetLimits(); SetLimits2(); }
    int16_t GetPosition() { return offsetPosition;} // primary
    int16_t GetPosition2() { return offsetPosition2;} // secondary
    uint8_t loop(int32_t &pos, int32_t &pos2);
    void SetLimits(int32_t lowLimit=LOWEST_INT32, int32_t highLimit = HIGHEST_INT32)
    { limitLow = lowLimit; limitHigh = highLimit;}
    void SetLimits2(int32_t lowLimit=LOWEST_INT32, int32_t highLimit = HIGHEST_INT32)
    { limitLow2 = lowLimit; limitHigh2 = highLimit;}
    void update();

    enum { BITMASK = (1 << ENC_PLUS) | (1 << ENC_MINUS)};
private:
    // non are volatile because interrupts are always off when accessed
    int32_t referencePosition;
    int16_t offsetPosition;
    int32_t referencePosition2;
    int16_t offsetPosition2;
    int32_t prevLoopPos;
    int32_t prevLoopPos2;
    uint8_t lastEncoder;
    int32_t limitLow;
    int32_t limitHigh;
    int32_t limitLow2;
    int32_t limitHigh2;
};
static volatile uint8_t forceEncoderUpdate;

namespace {
    Twi::Adafruit_Trellis matrix0 = Twi::Adafruit_Trellis();
    Twi::Adafruit_TrellisSet trellis = Twi::Adafruit_TrellisSet(&matrix0);

    /* We arrange for the different processors to have the
    ** same inputs on the same ports/pins (PORTB, bits 0 through 5)
    ** on the two processor architectures so we don't need conditional compile to
    ** read the pins*/
#if defined (__AVR_ATmega2560__) // NOT FULLY SUPPORTED BELOW
    /* Mega 2560. Useful for debugging cuz has extra serial ports   
    ** https://www.arduino.cc/en/uploads/Hacking/PinMap2560big.png
    ** Mega development board assignments chosen to make the software
    ** match the target 328 hardware as close as possible. */
    const int ENCODER1_PLUS_PIN = 11; // PORTB PCINT5
    const int ENCODER1_MINUS_PIN = 10;  // PORTB PCINT4
    const int ENCODER2_PLUS_PIN = A9; // PCINT17 - PORTK bit 1
    const int ENCODER2_MINUS_PIN = A8; // PCINT16 = PORTK bit 0
    const int ENCODER3_PLUS_PIN = 50; // PORTB, bit 3
    const int ENCODER3_MINUS_PIN = 51; // PORTB, bit 2
    const int ENCODER4_MINUS_PIN = 53; // PORTB, bit 0
    const int ENCODER4_PLUS_PIN = 52; // PORTB, bit 1

    const int ENCODER4_SWITCH_PIN = A7; 
    const int ENCODER2_SWITCH_PIN = 5;
    const int ENCODER3_SWITCH_PIN = 7;

#elif defined(__AVR_ATmega328P__)
    /* PRO MINI    
    ** https://www.arduino.cc/en/Hacking/PinMapping168 */
    const int ENCODER1_PLUS_PIN = 6; // PCINT22 -- PORTD
    const int ENCODER1_MINUS_PIN = 5; // PCINT21 -- PORTD
    const int ENCODER2_PLUS_PIN = 15; //PCINT 9 -- PORTC
    const int ENCODER2_MINUS_PIN = 14; //PCINT 8 -- PORTC
    const int ENCODER3_PLUS_PIN = 11; // PCINT3 -- PORTB
    const int ENCODER3_MINUS_PIN = 10; // PCINT2 -- PORTB
    const int ENCODER4_MINUS_PIN = 8; // PortB bit 0
    const int ENCODER4_PLUS_PIN = 9;   // PortB bit 1

    const int ENCODER2_SWITCH_PIN = 12;
    const int ENCODER3_SWITCH_PIN = 7;
    const int ENCODER4_SWITCH_PIN = A7; // use this one last. its analog only

    const int CWDOT_PIN = 3;
    const int CWDASH_PIN = 2;
    const int FOOTTIP_PIN = 16;

#else
#error "CPU not supported"
#endif
    const int NUMTRELLISKEYS = 16; // Trellis hardware can go beyond 16, but we don't
    const int NUM_ENCODER_SWITCHES = NUMBER_OF_ROTARY_ENCODERS - 1; // All but first
    // map both trellis and encoder switches to Genie
    const int NUM_DISPLAY_MAPS = NUMTRELLISKEYS + NUM_ENCODER_SWITCHES; 

    // The TWI_MASTERSLAVE_PIN is used to keep the ft232h i2c interface
    // off the i2c bus. the ft232h does NOT do multi-master arbitration, but
    // does support a 3rd wire "wait for" hardware handshake.
    const int TWI_MASTERSLAVE_PIN = 17; //ft232H 
    const int CWOUTPUT_PIN = 13;

#if defined(DO_GENIE)
#define GENIE_SHIELD_INVERTS_RESET 0 // either zero (with no shield) or 1--with shield
    // use only open-collector pull down on the GENIE_RESET_PIN, regardless of shield
    // The genie shield hardware is only used for debugging. This inverts-reset
    // compile-time stuff is due to the fact that the shield adds an open-collector
    // that you don't get without it...
    const int GENIE_RESET_PIN = 4;  // per the 4D systems shield
#endif

    // *********************************************************************
    // 3 of the 4 encoders have momentary push-in switches. 
    // We record a 1 in encoderSwitches while the switch is pushed down
    // ...which, with our pullup wiring, is a zero on our input pin
    const uint8_t encoder1SwitchMask = 0; // there is no encoder 1 switch
    const uint8_t encoder2SwitchMask = 1;
    const uint8_t encoder3SwitchMask = 2;
    const uint8_t encoder4SwitchMask = 4;

#if NUMBER_OF_ROTARY_ENCODERS > 0
#if defined (__AVR_ATmega2560__)
    const uint8_t ENCODER1_PLUS_BITNUM = 5;
    const uint8_t ENCODER1_MINUS_BITNUM = 4; 
#elif defined(__AVR_ATmega328P__)
    const uint8_t ENCODER1_PLUS_BITNUM = 6;
    const uint8_t ENCODER1_MINUS_BITNUM = 5; 
#endif
    QuadratureEncoder<ENCODER1_PLUS_BITNUM, ENCODER1_MINUS_BITNUM, encoder1SwitchMask> 
        encoder1;
#if NUMBER_OF_ROTARY_ENCODERS > 1
    const uint8_t ENCODER2_PLUS_BITNUM = 1;
    const uint8_t ENCODER2_MINUS_BITNUM = 0;
    QuadratureEncoder<ENCODER2_PLUS_BITNUM, ENCODER2_MINUS_BITNUM, encoder2SwitchMask> 
        encoder2;
#if NUMBER_OF_ROTARY_ENCODERS > 2
    void ReadEncoders3And4(); // read these two. however
    const uint8_t ENCODER3_PLUS_BITNUM = 3;
    const uint8_t ENCODER3_MINUS_BITNUM = 2;
    QuadratureEncoder<ENCODER3_PLUS_BITNUM, ENCODER3_MINUS_BITNUM, encoder3SwitchMask> 
        encoder3;
#if NUMBER_OF_ROTARY_ENCODERS > 3
    const uint8_t ENCODER4_PLUS_BITNUM = 1;
    const uint8_t ENCODER4_MINUS_BITNUM = 0;
    QuadratureEncoder<ENCODER4_PLUS_BITNUM, ENCODER4_MINUS_BITNUM, encoder4SwitchMask> 
        encoder4;
#endif
#endif
#endif
#endif
}

// debug LED output byte
extern "C" uint8_t WhereAmI;
uint8_t WhereAmI;

namespace cw {
    void setup();
    void loop();
}

namespace PcHost {
    // The i2c address the PC will use to address us as slave
    const int myI2cSlaveAddr = 42; // the answer to the question

    // message ID's host to us.
    const byte NO_COMMAND = 0;
    const byte ID_YOURSELF = 1;
    const byte LONG_TEST = 2;
    const byte SHORT_TEST = 3;
    const byte GET_ID_STRING = 4;
    const byte SET_ID_STRING = 5;
    const byte GET_INPUT_STATE = 6;
    const byte SET_ENCODER_CENTER = 7; // one byte ID plus
    const byte SET_TRELLIS_GROUP = 8;
    const byte SET_ENCODER_MAP = 9;
    const byte SET_DISPLAY_STRING = 10;
    const byte PRESS_TRELLIS_BUTTON = 11;
    const byte SET_DISPLAY_OBJECTS = 12;
    const byte SET_TRELLIS_BRIGHTNESS = 13;
    const byte RESET_DISPLAY_DEFAULTS = 14;
    const byte SET_ENCODER_SWITCH_STATE = 15;
    const byte SET_LCD_IMAGE_NAME = 16;
    const byte GET_LCD_VERSION_STRING = 17;
    const unsigned ID_STRING_LEN = 30;
    struct IdString {
        char name[ID_STRING_LEN];
    };
}

enum eeprom_offset { EEPROM_IDSTRING,
EEPROM_TRELLIS_BRIGHTNESS = EEPROM_IDSTRING + PcHost::ID_STRING_LEN};

volatile uint8_t powerUpDefaults = 1;

#if defined(DO_TRELLIS)
namespace Trellis {
    void clear()
    {
       // light up all the LEDs in order. startup display
        for (uint8_t i = 0; i < NUMTRELLISKEYS; i++) {
            trellis.setLED(i);
            if (i > 0) trellis.clrLED(i - 1);
            trellis.writeDisplay();
            delay(50);
        }
        trellis.clrLED(NUMTRELLISKEYS - 1);
        trellis.writeDisplay();
    }
}
#endif

namespace {
    /* This firmware treats the genie display as generic. We do a hardware
    ** reset initialization of a couple of mappings, but the map between the
    ** physical input devices and the display objects can be updated by
    ** calls through our USB interface*/
    struct GenieObject {
        GenieObject() : object(uint16_t(-1)), index(0){}
        GenieObject(uint16_t o, uint16_t i) : object(o), index(i){}
        bool isValid() const { return static_cast<int16_t>(object) != -1;}
        void markInvalid() { object = -1; }
        bool operator == (const GenieObject &o) const { return object == o.object && index == o.index;}
        bool operator != (const GenieObject &o) const { return object != o.object || index != o.index;}
            uint16_t object;
            uint16_t index;
    };
    const int RUNFLASH_NAME_LEN = 12; // 8.3 DOS file name
}

//#define CW_PIN_STATE_DISPLAY

namespace GenieRc1101 {
    const int GENIE_NAK_RETRIES = 2;
    const int GENIE_STARTUP_MSEC = 1900; 
    const int GENIE_RESET_MSEC = 50;
    static const int LOAD_RATE = 9600;
    static const int READY_MSG_LEN = 16;

#ifdef CW_PIN_STATE_DISPLAY
    int LedFlash;
    long FlashStarted;
#endif

    const char LCD_READY[READY_MSG_LEN] PROGMEM = {"RC1101-LCD READY"};
    class LoadableGenie {
#if defined(DO_GENIE)
        enum {IDLE, LOADING, VERIFY, LOAD_IN_PROGRESS,  RUNNING };

    public:
        LoadableGenie() : state(IDLE), fileNameSet(false) {
            memset(RunFlashFileName, 0, sizeof(RunFlashFileName));
        }

        void setup() // called only once
        {   // hold LCD's reset pin in reset state

            // If NOT using a 4D Arduino Adaptor, digitalWrites must be reversed as Display Reset is Active Low, and
            // the 4D Arduino Adaptors invert this signal so must be Active High.  
#if GENIE_SHIELD_INVERTS_RESET
            // the 4D Arduino Adaptors invert this signal so must be Active High.  
            digitalWrite(GENIE_RESET_PIN, LOW);  // unReset the Display via D4
            pinMode(GENIE_RESET_PIN, OUTPUT);  // Set D4 on Arduino to Output (4D Arduino Adaptor V2 - Display Reset)
#else
            //  NOT using a 4D Arduino Adaptor, the GENIE_RESET_PIN must NOT be driven HIGH. It is a 3.3V part!
            // It has an external pullup, so drive it LOW...  
            pinMode(GENIE_RESET_PIN, INPUT);  // ... let the display pull its reset line back high
#endif
            Serial.begin(LOAD_RATE);
            state = IDLE;
        }  

        loop(long now)
        {
#ifdef CW_PIN_STATE_DISPLAY
            if (now > FlashStarted + 600)
                switchState(state);
            else if (now > FlashStarted + 60)
            {
                if (digitalRead(CWOUTPUT_PIN) == HIGH)
                {
                    digitalWrite(CWOUTPUT_PIN, LOW);
                    if (LedFlash > 0)
                    {
                        LedFlash -= 1;
                        FlashStarted = now;
                    }
                }
                else if (LedFlash > 0)
                {
                    FlashStarted = now;
                    digitalWrite(CWOUTPUT_PIN, HIGH);
                }
            }
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
    void loop()
    {
        static long CwTimer;
        static uint8_t toFlash;
        static uint8_t print;

        long now = millis(); // refresh current time cuz stuff above takes time

        if ((int)(now - CwTimer) > 0)
        {
            if (CwState < (toFlash+1)<<1)
            {   // for toFlash:
                //       0 -> 0,1
                //       1 -> 0,1,2,3
                //       2 -> 0,1,2,3,4,5
                CwState += 1;
                if (print > 4) // flash quickly at 4 and above
                    CwTimer = now + 50;
                else
                    CwTimer = now + 300 + ((CwState % 8 == 0) ? 100 : 0);
            } else
            {
                CwState = 0;
                CwTimer = now + 1000;
                if (print == 0)
                {
                    toFlash = WhereAmI;
                    print = 1;
                }
                else if (print == 1)
                {
                    toFlash = static_cast<uint8_t>(i2Cstate);
                    print = 2;
                }
                else if (print == 2)
                {
                    toFlash = encoderSwitches;
                    print = 3;
                }
                else if (print == 3)
                {
                    toFlash = 0x7 & ((Trellis::switches) >> 8);
                    print = 4;
                }
                else if (print == 4)
                {
                    toFlash = 0;
                    print = 5;
                    CwTimer += 3000;
                }
                else if (print == 5)
                {
                    print = 0;
                    CwTimer = now;
                }
            }
        }    
    }
    void on512usec()
    {
        // FIXME
        cw::loop(); // DIAGNOSTICS only
#if 0
        static uint8_t osc;
        static const uint8_t CYCLES_ON = 1;
        static const uint8_t CYCLES_OFF = 6;
        static bool isOn;
        if ((1 & CwState) == 0)
        {
            isOn = false;
            digitalWrite(CWOUTPUT_PIN, LOW);
            osc = CYCLES_ON;
        }
        else
        {
            osc -= 1;
            if (osc == 0)
            {
                digitalWrite(CWOUTPUT_PIN, isOn ? LOW : HIGH);
                isOn = !isOn;
                osc = isOn ? CYCLES_ON : CYCLES_OFF;
            }
        }
#else
        //digitalWrite(CWOUTPUT_PIN, (1 & CwState) == 0 ? LOW : HIGH);
#endif
    }

#if (F_CPU == 16000000ul)
    const uint8_t USEC_512_COUNT = 0x80u; // 256 counts at 2uSec
#elif (F_CPU == 8000000ul)
    const uint8_t USEC_512_COUNT = 0x40u; // 128 counts at 4uSec
#else
#error Only support 16MHz and 8Mhz clocks
#endif

#if defined  (__AVR_ATmega328P__) || defined (__AVR_ATmega2560__)
    // target hardware is Pro Mini, which is 328P
    uint8_t tcnt2Setting()
    {
        return static_cast<uint8_t>(0x100u - USEC_512_COUNT); //counts up from here, interrupt at == 0
    }

    ISR(TIMER2_OVF_vect)
    {
        TCNT2 = tcnt2Setting();
        on512usec();
#if ENCODER3_AND_4_HANDLING==2
        ReadEncoders3And4();
#endif
    }
    void setup()
    {
        digitalWrite(CWOUTPUT_PIN, LOW);
        pinMode(CWOUTPUT_PIN, OUTPUT);
        noInterrupts();
        /* Normal timer operation.*/
        TCCR2A = 0x00;
        /* The timer counter register.         */
        TCNT2 = tcnt2Setting();
        TCCR2B = 0x04; // 64 prescale, which is 2usec per TCNT2 @ 16MHz
        /* Enable the timer overflow interrupt. */
        TIMSK2 = 0x01;
        TIFR2 = 1; // Clear any current overflow flag
        interrupts();
    }
#else
#error "Unsupported CPU for timer2"
#endif
}

#if NUMBER_OF_ROTARY_ENCODERS > 0
#if defined  (__AVR_ATmega328P__)
#if NUMBER_OF_ROTARY_ENCODERS > 2
#if ENCODER3_AND_4_HANDLING==1 // POLL portB cuz we get a crash on interrupts
ISR (PCINT0_vect) 
{
    // one of pins PCINT0 through PCINT7 has changed
    ReadEncoders3And4();
}
#endif
#endif

namespace {
#if NUMBER_OF_ROTARY_ENCODERS > 2
    void ReadEncoders3And4()
     {  // initialize encoders
        uint8_t v = PINB;
        encoder3.OnEncoder(v);
#if NUMBER_OF_ROTARY_ENCODERS > 3
        encoder4.OnEncoder(v);
#endif
    }
#endif
}

ISR (PCINT1_vect) 
{
    // one of pins PCINT8 through PCINT15 has changed
    uint8_t vc = PINC;
    encoder2.OnEncoder(vc);
}

ISR (PCINT2_vect) 
{
    // one of pins PCINT16 through PCINT23 has changed
    uint8_t vc = PIND;
    encoder1.OnEncoder(vc);
}

#elif defined (__AVR_ATmega2560__)
ISR (PCINT0_vect) 
{
    // one of pins PCINT0 through PCINT7 has changed
    uint8_t v = PINB;
    encoder1.OnEncoder(v);
#if NUMBER_OF_ROTARY_ENCODERS > 2
    encoder3.OnEncoder(v);
#if NUMBER_OF_ROTARY_ENCODERS > 3
    encoder4.OnEncoder(v);
#endif
#endif
}
ISR (PCINT2_vect) 
{
    // one of pins PCINT16 through PCINT23 has changed
    uint8_t vc = PINK;
    encoder2.OnEncoder(vc);
}
#endif
#endif

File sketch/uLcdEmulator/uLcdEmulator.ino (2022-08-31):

/* running on Arduino Mega, connect these three pins to the LCD connector 
** on the RC-1101 PCB:
**      Mega            RC-1101
**        21             RES
**        20             GND
**        19             TXD
**        18             RXD
**
**        23            RESET on removed FT232 socket
*/
/*
Typical printout:
Start reset sequence
2351 LCD reset asserted
state change to Reset Asserted
51 state change to Reset Released
RC1101-LCD READY
Incoming fn="RunFlash.4xe"
10022009 OK
state change to Running
1902 Write Contrast
0 Write Object type=10 idx=0
**
** total is about 4.5 seconds....
** the Arduino is processing the i2c at about 2.4 seconds
** This sketch responds to its reset from the arduino instantaneously...
** The physical LCD display takes about 4 seconds to respond 
** and get to its "RC1101-LCD READY" report (its not processing genie yet)
** 
** The timeline with real parts is this:
** Arduino RESET to LCD reset is about 2.5 seconds
** LCD reset to "RC1101-LCD READY" is a measured 2.9 seconds
** The wlRemoteGeneric sketch notes that READY message and holds 1.9 seconds
** before sending any commands to the LCD.
*/


const int GROUND_PIN = 20;
const int RESET_INPUT = 21;
const int RC1101_RESET_OUTPUT = 23;

const long LOADER_BAUD = 9600;
const long RUN_BAUD = 200000;

enum emState_t {RESET_IN_ASSERTED, RESET_IN_RELEASED, RUNNING} emState = RESET_IN_RELEASED;

static const char * const StateNames[] =
{"Reset Asserted", "Reset Released", "Running"};

void setup()
{
    Serial.begin(9600);
    Serial.println("uLcdEmulator");
    Serial1.begin(LOADER_BAUD);
    pinMode(RESET_INPUT, INPUT_PULLUP);
    digitalWrite(GROUND_PIN, LOW);
    pinMode(GROUND_PIN, OUTPUT);
    pinMode(RC1101_RESET_OUTPUT, INPUT);
    digitalWrite(RC1101_RESET_OUTPUT, LOW);
}

void setState(emState_t n)
{
    if (emState != n)
    {
        Serial.print("state change to "); 
        Serial.println(StateNames[n]);
    }
    emState = n;
}

const int LCD_BUF_LEN = 80;
const int FILENAME_LEN = 12;
static char LcdInBuf[LCD_BUF_LEN];
int charsInLcdBuf;

const int DBG_BUF_LEN = 80;
static char DbgInBuf[DBG_BUF_LEN];
int charsInDbgBuf;

bool ProcessLcd(int diff)
{
    bool ret = false;
    while (charsInLcdBuf > 0)
    {
        int used = 0;
        switch (LcdInBuf[0])
        {
        case 0x4: //write contrast
            if (charsInLcdBuf < 3)
                return ret;
            used = 3;
            Serial1.write(6);
            Serial.print(diff);
            Serial.println(" Write Contrast");
            break;
        case 0x1:
            if (charsInLcdBuf < 6)
                return ret;
            used = 6;
            Serial1.write(6);
            Serial.print(diff);
            Serial.print(" Write Object type=");
            Serial.print((int) LcdInBuf[1]);
            Serial.print(" idx="); 
            Serial.println((int) LcdInBuf[2]);
            break;
        default:
            Serial.print(diff);
            Serial.print(" Unknown command 0x");
            Serial.println((int)(unsigned char)LcdInBuf[0], HEX);
            used = charsInLcdBuf;
            break;
        }
        if (used > 0)
        {
            ret = true;
            if (used < charsInLcdBuf)
                memmove(LcdInBuf, LcdInBuf + used, charsInLcdBuf - used);
            charsInLcdBuf -= used;
        }
    }
    return ret;
}

unsigned long runStateTransition;
void LcdRun()
{
    Serial.print("Incoming fn=\"");
    for (int i = 0; i < charsInLcdBuf; i++)
        Serial.print(LcdInBuf[i]);
    Serial.println("\"");
    charsInLcdBuf = 0;

    static const char *Msg = "10022009 OK";
    Serial.println(Msg);
    Serial1.print(Msg); Serial1.print('\n');
    Serial1.flush();
    Serial1.end();
    Serial1.begin(RUN_BAUD);
    setState(RUNNING);
    runStateTransition = millis();
}

unsigned long inReleasedSince = 0x8000000;
void ProcessDbg()
{
    if (charsInDbgBuf > 0)
    {
        if (toupper(DbgInBuf[0]) == 'R')
        {
            Serial.println("Start reset sequence");
            inReleasedSince = millis();
            pinMode(RC1101_RESET_OUTPUT, OUTPUT);
            delay(50);
            pinMode(RC1101_RESET_OUTPUT, INPUT);
        }
    }
    charsInDbgBuf = 0;
}


void loop()
{
    while (Serial.available() > 0)
    {
        auto c = Serial.read();
        if (c == '\r')
            ProcessDbg();
        else if (charsInDbgBuf < DBG_BUF_LEN)
            DbgInBuf[charsInDbgBuf++] = c;
    }

    auto res = digitalRead(RESET_INPUT);
    auto now = millis();

    if (res == LOW)
    {
        if (emState != RESET_IN_ASSERTED)
        {
            Serial1.end();
            Serial1.begin(LOADER_BAUD);
            Serial.print(now - inReleasedSince);
            Serial.println(" LCD reset asserted");
            inReleasedSince = now;
        }
        setState(RESET_IN_ASSERTED);
    }
    else
    {
        switch(emState)
        {
        case RESET_IN_ASSERTED:
            Serial.print((int)(now - inReleasedSince));
            Serial.print(' ');
            setState(RESET_IN_RELEASED);
            // fall through

        case RESET_IN_RELEASED:
            if (now - inReleasedSince > 1000)
            {
                static const char *Msg = "RC1101-LCD READY";
                inReleasedSince = now;
                Serial.println(Msg);
                Serial1.print(Msg); Serial1.print('\n');
                charsInLcdBuf = 0;
            }
            while (Serial1.available() > 0)
            {
                auto c = Serial1.read();
                if (isspace(c))
                    LcdRun();
                else if (charsInLcdBuf < LCD_BUF_LEN)
                {
                    LcdInBuf[charsInLcdBuf++] = c;
                    if (charsInLcdBuf >= FILENAME_LEN)
                        LcdRun();
                }
            }
            break;

        case RUNNING:
            while (Serial1.available() > 0)
            {
                auto c = Serial1.read();
                int diff = now - runStateTransition;
                if (charsInLcdBuf < LCD_BUF_LEN)
                    LcdInBuf[charsInLcdBuf++] = c;                
                if (ProcessLcd(diff))
                     runStateTransition = now;
            }
            break;
        }

    }
}

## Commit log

2019-01-03 slope the Trellis which required the entire enclosure redesign
    [RC1101-3.SLDASM, RC1101-4.SLDASM, enclosure LCD back cover.STL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]
2019-01-03 make Z go up for enclosure2.STL
    [enclosure2.STL]
2019-01-17 latest enclosure clearance limits
2019-01-17 enclosure cleanup photo
2019-02-05 Icom overlay to match current firmware
    [Overlay-Icom.STL]
2019-02-16 correct font
    [Overlay-Icom.SLDPRT, Overlay-Icom.STL]
2019-06-19 gen4 support
    [1051330001.SLDPRT, 2x15Header.sldprt, 2x5Header.sldprt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]
2019-06-19 convert 4d workshop items to gen4
    [RUNRC1101.cfg, WLRemoteGeneric.cfg]
2019-06-24 as Flex6000 overlay
    [Overlay-Flex6000.SLDPRT, Overlay-Flex6000.STL]
2019-06-24 Flex-6000 support for RC-1101
    [WLRemoteGeneric.cfg]
2019-06-25 config file
    [WLRemoteGeneric.cfg]
2020-03-09 checkpoint. Adafruit changed their 2264 part to USB-C. its taller!
    [Ft232H-2-assembly.SLDASM, PcbWithParts.SLDASM, RC1101-4.SLDASM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]
2020-03-31 new Adafruit RS232H part
    [Ft232H-2-assembly.SLDASM, PcbWithParts.SLDASM, RC1101-4.SLDASM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]
2020-05-15 add support for downloadable 4xe
    [Overlay-Icom.SLDPRT, Overlay-TS590.SLDPRT, Overlay-TS590.STL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]
2020-05-15 gerber files for REV4 PCB
2020-05-18 rearrange ts590 keypad
    [Overlay-Icom.STL, Overlay-TS590.SLDPRT, Overlay-TS590.STL]
2020-06-10 overlays consistent with WL12.50
    [Overlay-Flex6000.SLDPRT, Overlay-Flex6000.STL, Overlay-Generic.SLDPRT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]
2020-09-17 STL coords for overlays
    [Overlay-Flex6000.SLDPRT, Overlay-Flex6000.STL, Overlay-Generic.SLDPRT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]
2024-01-12 blank overlay
    [Overlay-Blank.stp]
